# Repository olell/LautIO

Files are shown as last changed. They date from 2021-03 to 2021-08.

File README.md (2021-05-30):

# LautIO
Mobile PA-System solution

## Hardware Features

- [x] ESP32 (WiFi + Bluetooth)
- [x] ADAU1701 Digital Signal Processor
- [x] 12V, 5V & 3.3V Power Supply from Battery
- [x] 2x TPA3255-Q1 Amplifier (615W each -> 1260W Amp Power)
- [x] USB Ports to charge mobile phones, etc.
- [x] SD Card socket

## Fancy Rendering
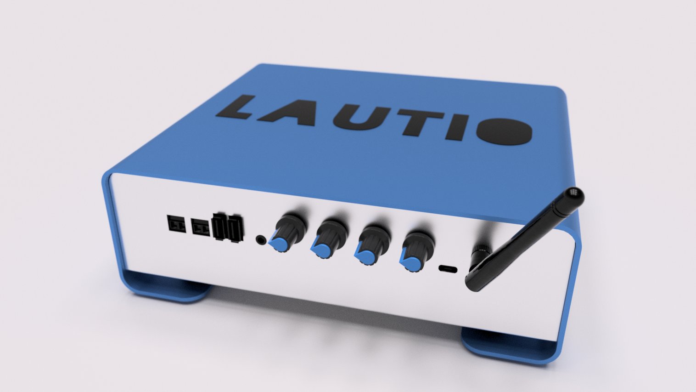
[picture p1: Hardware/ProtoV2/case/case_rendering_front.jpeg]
LautIO Rendering


## Third party resources
This git repository contains links or files of the following projects:
* `Bootstrap 5` released under the MIT license. (c) 2021 Twitter
* `Bootswach` released under the MIT license. (c) 2021 Thomas Park
* `jQuery 3.6.0` released under the MIT license. (c) 2021 OpenJS Foundation
* `PlatformIO` released under the Apache 2.0 license. (c) 2021 PlatformIO
* `ESPAsyncTCP` released under the GNU LGPL license. (c) 2021 https://github.com/me-no-dev
* `ESPAsyncWebServer` released under the GNU LGPL license. (c) 2021 https://github.com/me-no-dev
* `SigmaDSP library` released under the GNU LGPL license. (c) 2021 https://github.com/MCUdude
* `ArduinoJson library` released under the MIT license. (c) 2021 Benoît Blanchon

## License
MIT License

Copyright (c) 2021 olel

Permission is hereby granted, free of charge, to any person obtaining a copy
of this software and associated documentation files (the "Software"), to deal
in the Software without restriction, including without limitation the rights
to use, copy, modify, merge, publish, distribute, sublicense, and/or sell
copies of the Software, and to permit persons to whom the Software is
furnished to do so, subject to the following conditions:

The above copyright notice and this permission notice shall be included in all
copies or substantial portions of the Software.

THE SOFTWARE IS PROVIDED "AS IS", WITHOUT WARRANTY OF ANY KIND, EXPRESS OR
IMPLIED, INCLUDING BUT NOT LIMITED TO THE WARRANTIES OF MERCHANTABILITY,
FITNESS FOR A PARTICULAR PURPOSE AND NONINFRINGEMENT. IN NO EVENT SHALL THE
AUTHORS OR COPYRIGHT HOLDERS BE LIABLE FOR ANY CLAIM, DAMAGES OR OTHER
LIABILITY, WHETHER IN AN ACTION OF CONTRACT, TORT OR OTHERWISE, ARISING FROM,
OUT OF OR IN CONNECTION WITH THE SOFTWARE OR THE USE OR OTHER DEALINGS IN THE
SOFTWARE.

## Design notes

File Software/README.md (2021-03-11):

# LautI/O Software

This directory contains thie soft-/ firmware.

* `LautIO/`: This is the PlatformIO firmware project for the esp32

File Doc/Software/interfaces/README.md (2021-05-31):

# Interfaces
You can control the LautIO via different interfaces..

following interfaces are currently implemented:
* Websockets

## Base structure
```JSON
{
    "category": "example",
    "command": "example_command",
    "parameter": "xyz",
    "more_param": 123,
    "value": true
}
```

## Categories
* [`DSP`](dsp.md)

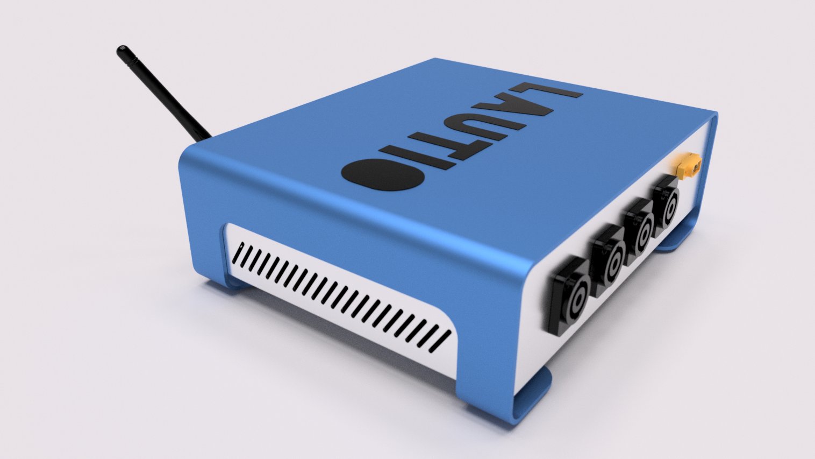
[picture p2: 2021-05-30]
Hardware/ProtoV2/case/case_rendering_back.jpeg

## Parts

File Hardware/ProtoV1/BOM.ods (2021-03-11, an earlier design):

Part | Value | Package | Amount | Mouser No. |  | Labels
 |  |  | 169
Electrolytic Cap | 10000 µF | EB35D | 1 | 80-ALC10S1103DH | Mouser Link (https://www.mouser.de/ProductDetail/) | C1
Electrolytic Cap | 10 µF | 153CLV-0605 | 3 | 667-EEE-FN1J100L | Mouser Link (https://www.mouser.de/ProductDetail/) | C2, C10, C11
Cap | 1.2 nF | 0603 | 1 | 80-C0603C122K5R | Mouser Link (https://www.mouser.de/ProductDetail/) | C3
Cap | 6.8 pF | 0603 | 1 | 80-C0603C689K5G | Mouser Link (https://www.mouser.de/ProductDetail/) | C4
Cap | 100 nF | 0603 | 26 | 80-C0603C104M5R | Mouser Link (https://www.mouser.de/ProductDetail/) | C5, C7, C9, C14-C21, C27, C29, C31, C43, C45, C46, C48, C52, C54, C67, C69, C70, C72, C76, C78
Electrolytic Cap | 47 µF | 153CLV-0807 | 1 | 667-EEE-FK1J470L | Mouser Link (https://www.mouser.de/ProductDetail/) | C6
Cap | 2.2 nF | 0603 | 1 | 80-C0603C222M5R | Mouser Link (https://www.mouser.de/ProductDetail/) | C8
Polarized Cap | 10 µF | 1206 | 11 | 187-CL31A106KBHNNNE | Mouser Link (https://www.mouser.de/ProductDetail/) | C12, C13, C22-C24, C28, C30, C44, C47, C68, C71
Cap | 22 pF | 0603 | 2 | 80-C0603C220M5HACTU | Mouser Link (https://www.mouser.de/ProductDetail/) | C25, C26
Polarized Cap | 47 µF | 1206 | 1 | 963-EMK316BBJ476ML-T | Mouser Link (https://www.mouser.de/ProductDetail/) | C32
Cap | 3.3 nF | 0603 | 1 | 80-C0603C332K5R | Mouser Link (https://www.mouser.de/ProductDetail/) | C33
Cap | 56 nF | 0603 | 1 | 80-C0603C563K5RAUTO | Mouser Link (https://www.mouser.de/ProductDetail/) | C34
Electrolytic Cap | 47 µF | CLV-0605 | 4 | EEE-FK1V470AL | Mouser Link (https://www.mouser.de/ProductDetail/) | C35, C37, C39, C41
Cap | 5.6 nF | 0603 | 4 | 80-C0603C562K5R | Mouser Link (https://www.mouser.de/ProductDetail/) | C36, C38, C40, C42
Electrolytic Cap | 1000 µF | E7,5-16 | 4 | 667-ECA-1JM102B | Mouser Link (https://www.mouser.de/ProductDetail/) | C49, C50, C73, C74
Cap | 1 µF | 0603 | 4 | 581-06035D105MAT2A | Mouser Link (https://www.mouser.de/ProductDetail/) | C51, C53, C75, C77
Cap | 1 µF | C3640 | 4 | 505-SMDTD04100XAKT00 | Mouser Link (https://www.mouser.de/ProductDetail/) | C60, C62, C84, C86
Cap | 330 pF | 0603 | 4 | 80-C0603C331M5HACTU | Mouser Link (https://www.mouser.de/ProductDetail/) | C55, C61, C79, C85
Cap | 220 nF | 0603 | 16 | 810-C1608X7R1H224K | Mouser Link (https://www.mouser.de/ProductDetail/) | C56-C59, C63-C66, C80-C83, C87-C90
Diode | STPS20M100SG-TR | D²PAK | 1 | 511-STPS20M100SG-TR | Mouser Link (https://www.mouser.de/ProductDetail/) | D1
ESP 32 |  |  | 1 | Nope don’t buy this at mouser :P | Mouser Link (https://www.mouser.de/ProductDetail/) | ESP
Regulator | *1117 | SOT223 | 1 | 511-LDL1117S33R | Mouser Link (https://www.mouser.de/ProductDetail/) | IC1
Inductor | 15 µH | 4747 | 1 | 994-MSS1210-153MEB | Mouser Link (https://www.mouser.de/ProductDetail/) | L1
Inductor | 1 µH |  | 1 | 710-74438357010 | Mouser Link (https://www.mouser.de/ProductDetail/) | L2
Inductor | L3-L10 |  | 8 | 710-744770115 | Mouser Link (https://www.mouser.de/ProductDetail/) | L3-L10
Transistor | ZX5T953 | SOT223 | 1 | 522-ZX5T953GTA | Mouser Link (https://www.mouser.de/ProductDetail/) | Q1
Crystal | 12.288 Mhz | ? | 1 | 520-122.8-20-3XENT | Mouser Link (https://www.mouser.de/ProductDetail/) | Q2
Regulator | TPS54560B-Q1 | HSOP8 | 1 | 595-TPS54560BQDDARQ1 | Mouser Link (https://www.mouser.de/ProductDetail/) | REG1
Regulator | TPS621351RGXR | RGX0011A ??? | 1 | 595-TPS621351RGXT | Mouser Link (https://www.mouser.de/ProductDetail/) | REG2
Momentary Switch |  | ? | 2 | 612-LL3303F065QG | Mouser Link (https://www.mouser.de/ProductDetail/) | S1, S2
XT60 |  | XT60 | 1 | 426-FIT0587 | Mouser Link (https://www.mouser.de/ProductDetail/) | U$1
Heatsink | ATS-CPX030030030 |  | 2 | 984-CPX03003-173C2R0 | Mouser Link (https://www.mouser.de/ProductDetail/) | U$2, U§3
DSP | ADAU1701 | ST_48_ADI ??? | 1 | 584-ADAU1701JSTZ | Mouser Link (https://www.mouser.de/ProductDetail/) | U1
Amp | TDA7498ETR | SSO36 | 2 | 511-TDA7498ETR | Mouser Link (https://www.mouser.de/ProductDetail/) | U2, U3
Connector | MKDSN1,5/2-5,08 | ? | 1 | 651-1985865 | Mouser Link (https://www.mouser.de/ProductDetail/) | X1
USB | Type A Up Right | ? | 2 | 649-73725-0110BLF | Mouser Link (https://www.mouser.de/ProductDetail/) | J1, J2
3.5 mm Jack | SJ1-3523N | CUI_SJ1-3523N | 1 | 490-SJ1-3523N | Mouser Link (https://www.mouser.de/ProductDetail/) | J5
Resistor | 187 kΩ | 0603 | 1 | 667-ERJ-3EKF1873V | Mouser Link (https://www.mouser.de/ProductDetail/) | R1
Resistor | 44.2 kΩ | 0603 | 1 | 667-ERJ-3EKF4422V | Mouser Link (https://www.mouser.de/ProductDetail/) | R2
Resistor | 147 kΩ | 0603 | 1 | 667-ERJ-3EKF1473V | Mouser Link (https://www.mouser.de/ProductDetail/) | R3
Resistor | 10.5 kΩ | 0603 | 1 | 667-ERJ-3EKF1052V | Mouser Link (https://www.mouser.de/ProductDetail/) | R4
Resistor | 100 kΩ | 0603 | 8 | 71-CRCW0603100KFKEAC | Mouser Link (https://www.mouser.de/ProductDetail/) | R5, R6, R31-R33, R45-R47
Resistor | 619 kΩ | 0603 | 1 | 667-ERJ-3EKF6193V | Mouser Link (https://www.mouser.de/ProductDetail/) | R7
Resistor | 10 kΩ | 0603 | 8 | 667-ERJ-3GEYJ103V | Mouser Link (https://www.mouser.de/ProductDetail/) | R8, R16, R26, R27, R30, R40, R41, R44
Resistor | 4.7 kΩ | 0603 | 2 | 667-ERJ-3EKF4701V | Mouser Link (https://www.mouser.de/ProductDetail/) | R13, R14
Resistor | 1 kΩ | 0603 | 1 | 71-CRCW06031K00JNEAC | Mouser Link (https://www.mouser.de/ProductDetail/) | R15
Resistor | 18 kΩ | 0603 | 3 | 667-ERJ-3EKF1802V | Mouser Link (https://www.mouser.de/ProductDetail/) | R17-R19
Resistor | 100 Ω | 0603 | 1 | 667-ERJ-3EKF1000V | Mouser Link (https://www.mouser.de/ProductDetail/) | R20
Resistor | 475 Ω | 0603 | 1 | 667-ERJ-3EKF4750V | Mouser Link (https://www.mouser.de/ProductDetail/) | R21
Resistor | 560 Ω | 0603 | 1 | 667-ERJ-3EKF5600V | Mouser Link (https://www.mouser.de/ProductDetail/) | R22-R25
Resistor | 22 Ω | 0603 | 6 | 667-ERJ-3EKF22R0V | Mouser Link (https://www.mouser.de/ProductDetail/) | R28, R34, R37, R42, R48, R51
Resistor | 47 kΩ | 0603 | 2 | 667-ERJ-3RBD4702V | Mouser Link (https://www.mouser.de/ProductDetail/) | R29, R43
Resistor | 8 Ω | 0603 | 8 | 71-CRCW06038R06FKEA | Mouser Link (https://www.mouser.de/ProductDetail/) | R35, R36, R38, R39, R49, R50, R52, R53
Potentiometer | 10 kΩ |  | 4 | 858-P160KN0QD15B10K | Mouser Link (https://www.mouser.de/ProductDetail/) | R9-R12

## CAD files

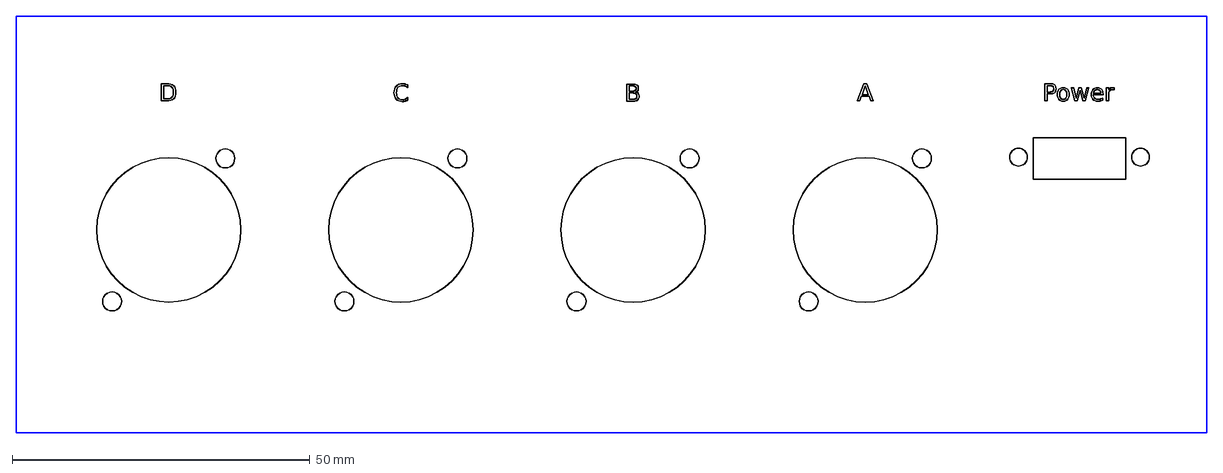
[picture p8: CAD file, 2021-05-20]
Hardware/ProtoV2/case/panel_rear_cutouts.dxf
199.9 x 69.9 mm

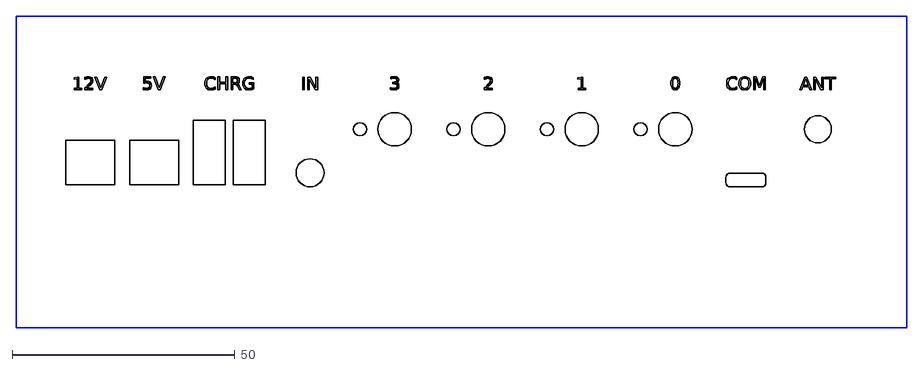
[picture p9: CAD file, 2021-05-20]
Hardware/ProtoV2/case/panel_front_cutouts.dxf
199.9 x 69.9

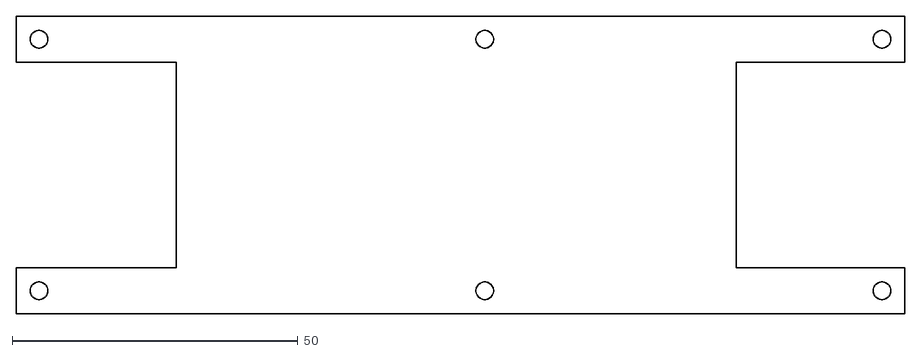
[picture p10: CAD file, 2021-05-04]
Hardware/ProtoV2/case/pipemount.dxf
155.5 x 52.0

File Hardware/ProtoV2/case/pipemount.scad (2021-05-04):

/*
 *
 * This file is part of LautIO
 *
 * Copyright 2021 - olel
 * LautIO is licensed under MIT License
 * See LICENSE file for more information
 * 
 */
 
 $fn = 60;
 
 plate_width           = 155.50;
 plate_height          = 52.00;
 
 screw_size            = 3.10;
 screw_distance        = 4.00;
 middle_screw_distance = 78.00;
 
 cutout_left_width     = 28.00;
 cutout_right_width    = 29.50;
 
 module pipemount() {
     difference() {
        
         // ground plane
         square([plate_width, plate_height]);
         
         union() {
             
             // screw holes
             translate([screw_distance, screw_distance])
             circle(d=screw_size);
             
             translate([screw_distance + middle_screw_distance, screw_distance])
             circle(d=screw_size);
             
             translate([plate_width - screw_distance, screw_distance])
             circle(d=screw_size);
             
             translate([plate_width - screw_distance, plate_height - screw_distance])
             circle(d=screw_size);
             
             translate([screw_distance, plate_height - screw_distance])
             circle(d=screw_size);
             
             translate([screw_distance + middle_screw_distance, plate_height - screw_distance])
             circle(d=screw_size);
             
             // left cutout
             translate([0, screw_distance * 2])
             square([cutout_left_width, plate_height - (screw_distance * 4)]);
             
             // right cutout
             translate([plate_width - cutout_right_width, screw_distance * 2])
             square([cutout_right_width, plate_height - (screw_distance * 4)]);
             
             
         }
     }
     
 }
 
 pipemount();

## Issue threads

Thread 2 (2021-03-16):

Cascading

olell, 2021-03-16:
Cascading von mehreren LautIO boards via SPDIF bzw. Toslink

olell, 2021-04-12:
Via I2S in protov2 schematic angepasst

Closed 2021-04-12.

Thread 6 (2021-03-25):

DSP Reset auf GPIO12

olell, 2021-03-25:
Flashen funktioniert mit DSP Reset auf GPIO12 nicht..

olell, 2021-04-12:
In protov2 schematic angepasst

Closed 2021-04-12.

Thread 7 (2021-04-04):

WiFi connect nur jedes zweite Mal

olell, 2021-04-04:
Könnte etwas ähnliches wie dieses sein: https://github.com/espruino/Espruino/issues/1168

olell, 2021-04-21:
Schreibe die software jetze eh neu, also erstmal geschlossen :)

Closed 2021-04-21.

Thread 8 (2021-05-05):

VBAT_MEASURE offset

olell, 2021-05-05:
Der VBAT_MEASURE OpAmp packt irgendwie nen Offset auf die geteilte Akkuspannung drauf.. lässt sich probably mit software austarieren

olell, 2021-07-15:
Ist nen hardware fehler, für ProtoV2 ist die einfachste Lösung den OpAmp zwischen ESP und Spannungsteiler einfach rauszulassen und zu Brücken

Closed 2021-07-15.

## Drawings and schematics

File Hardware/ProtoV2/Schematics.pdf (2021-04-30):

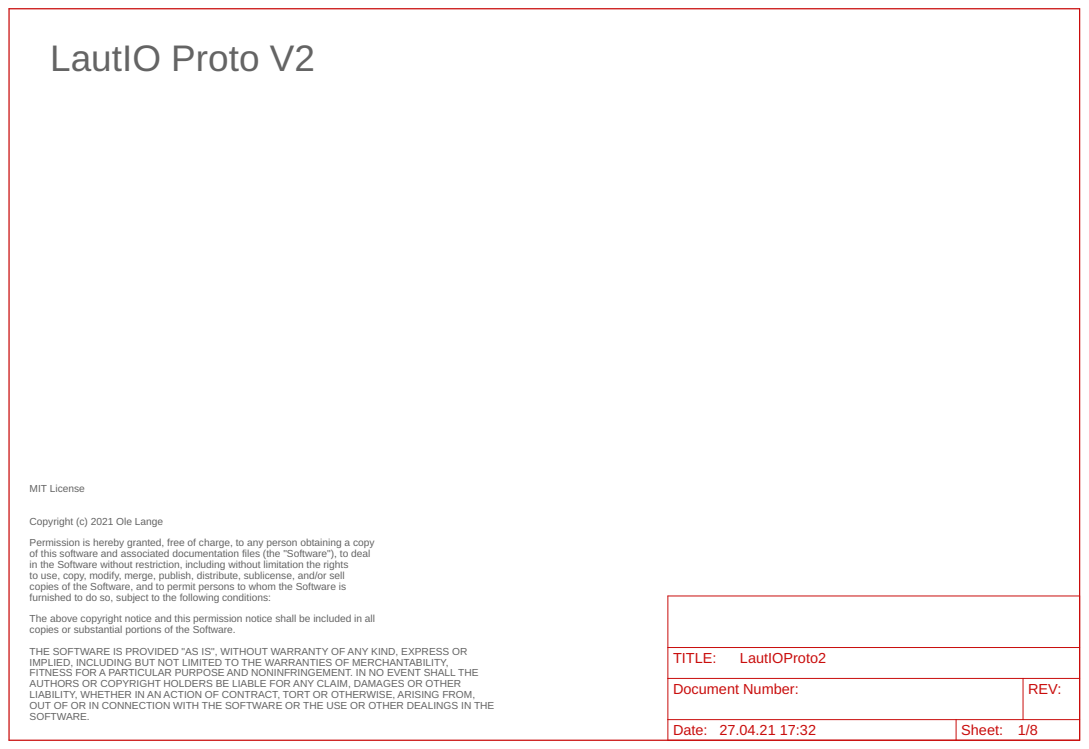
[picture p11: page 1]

MIT License Copyright (c) 2021 Ole Lange Permission is hereby granted, free of charge, to any person obtaining a copy of this software and associated documentation files (the "Software"), to deal

in the Software without restriction, including without limitation the rights
to use, copy, modify, merge, publish, distribute, sublicense, and/or sell copies of the Software, and to permit persons to whom the Software is

furnished to do so, subject to the following conditions: The above copyright notice and this permission notice shall be included in all copies or substantial portions of the Software. THE SOFTWARE IS PROVIDED "AS IS", WITHOUT WARRANTY OF ANY KIND, EXPRESS OR

IMPLIED, INCLUDING BUT NOT LIMITED TO THE WARRANTIES OF MERCHANTABILITY, FITNESS FOR A PARTICULAR PURPOSE AND NONINFRINGEMENT. IN NO EVENT SHALL THE

AUTHORS OR COPYRIGHT HOLDERS BE LIABLE FOR ANY CLAIM, DAMAGES OR OTHER
LIABILITY, WHETHER IN AN ACTION OF CONTRACT, TORT OR OTHERWISE, ARISING FROM, OUT OF OR IN CONNECTION WITH THE SOFTWARE OR THE USE OR OTHER DEALINGS IN THE

Document Number: | REV:

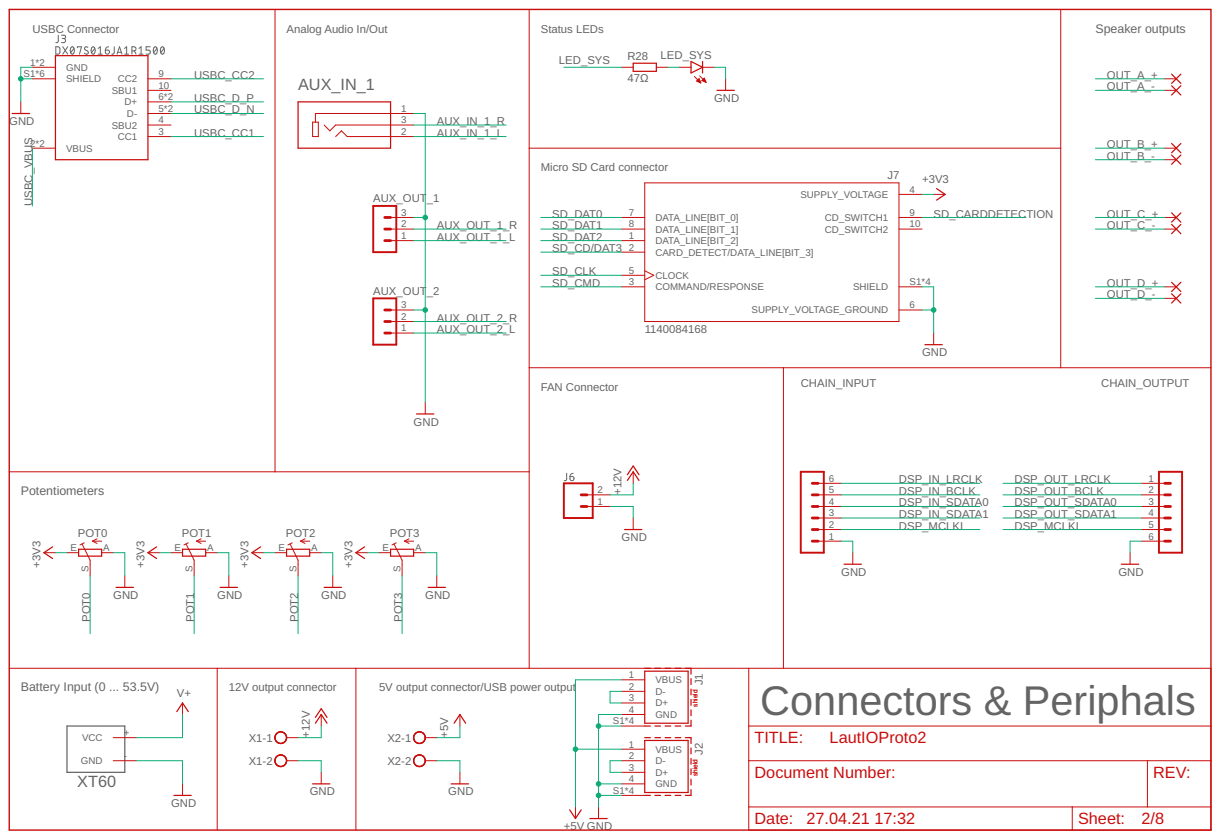
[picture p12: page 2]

Micro SD Card connector

5V output connector/USB power output

Document Number: | REV:

Date: | Sheet:

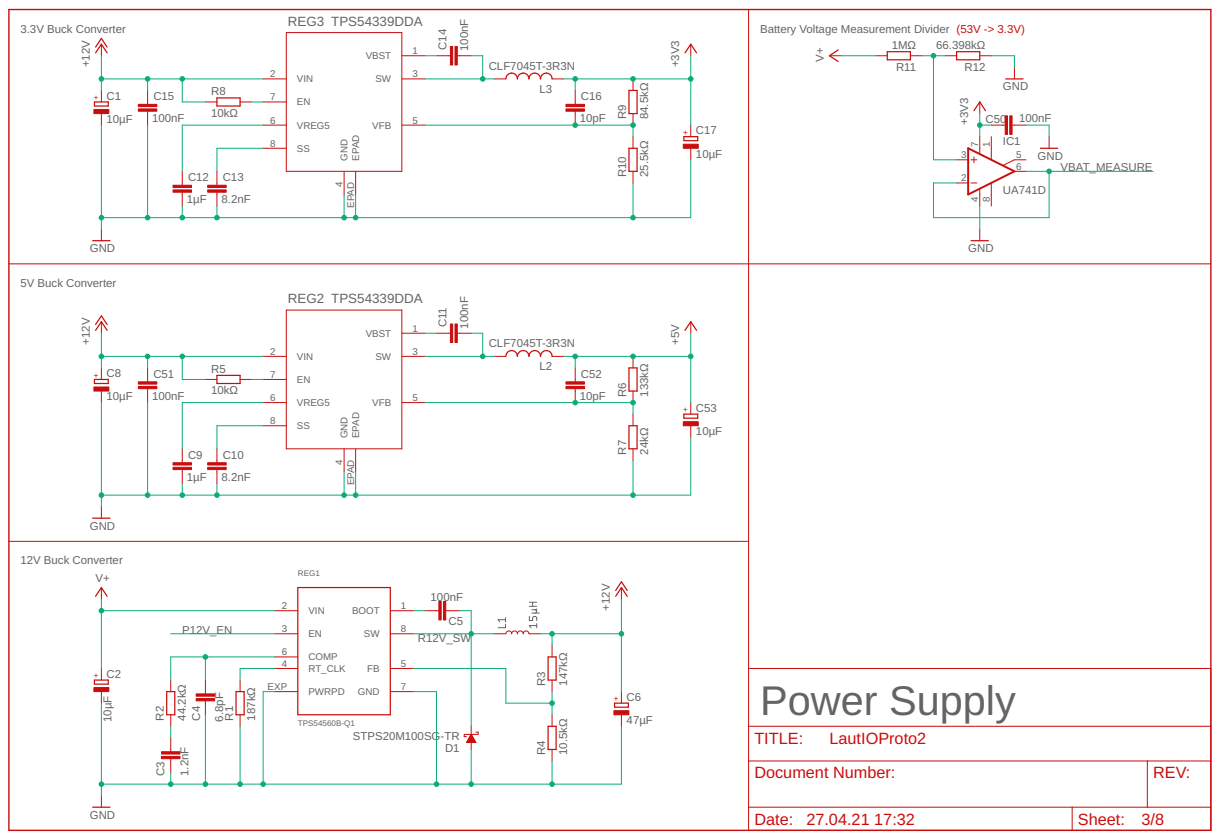
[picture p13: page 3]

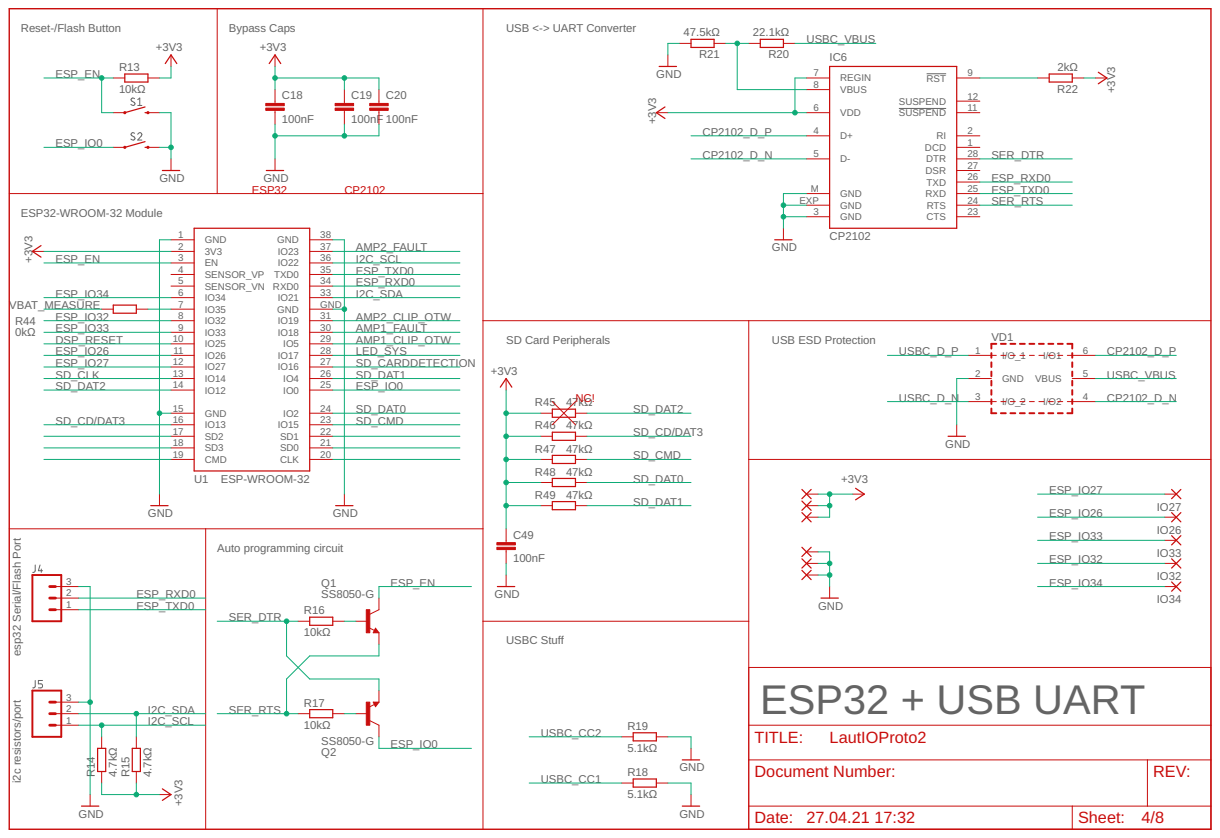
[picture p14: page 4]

esp32 Serial/Flash Port i2c resistors/port

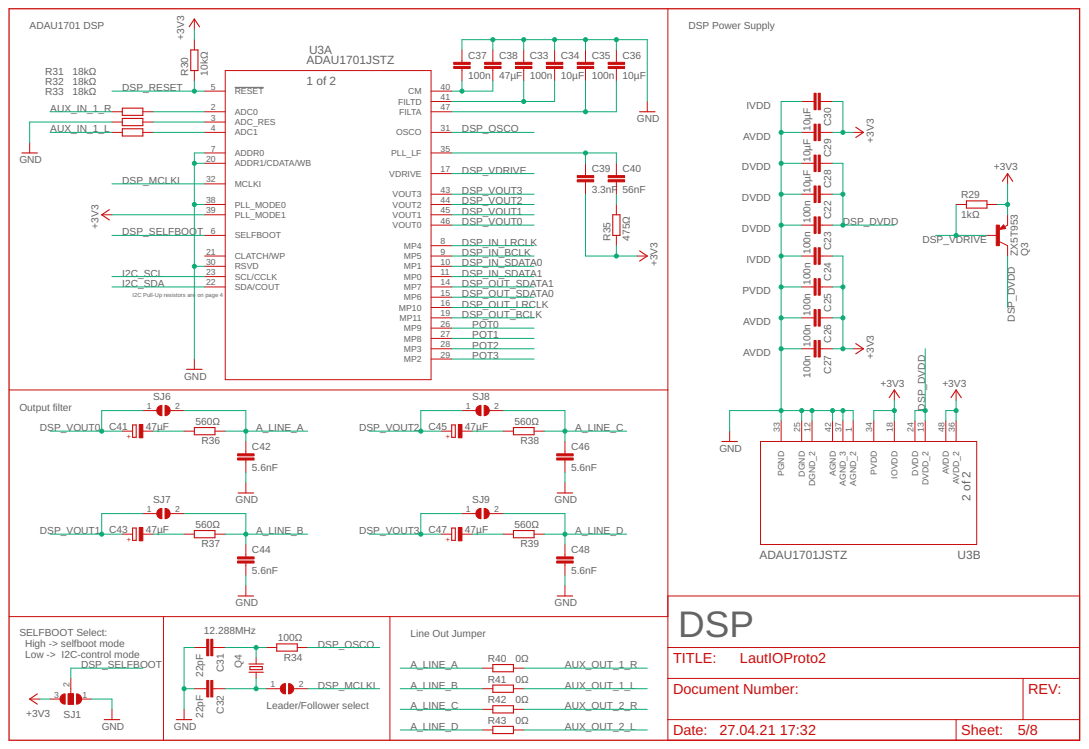
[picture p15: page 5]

I2C Pull-Up resistors are on page 4

SELFBOOT Select: High -> selfboot mode

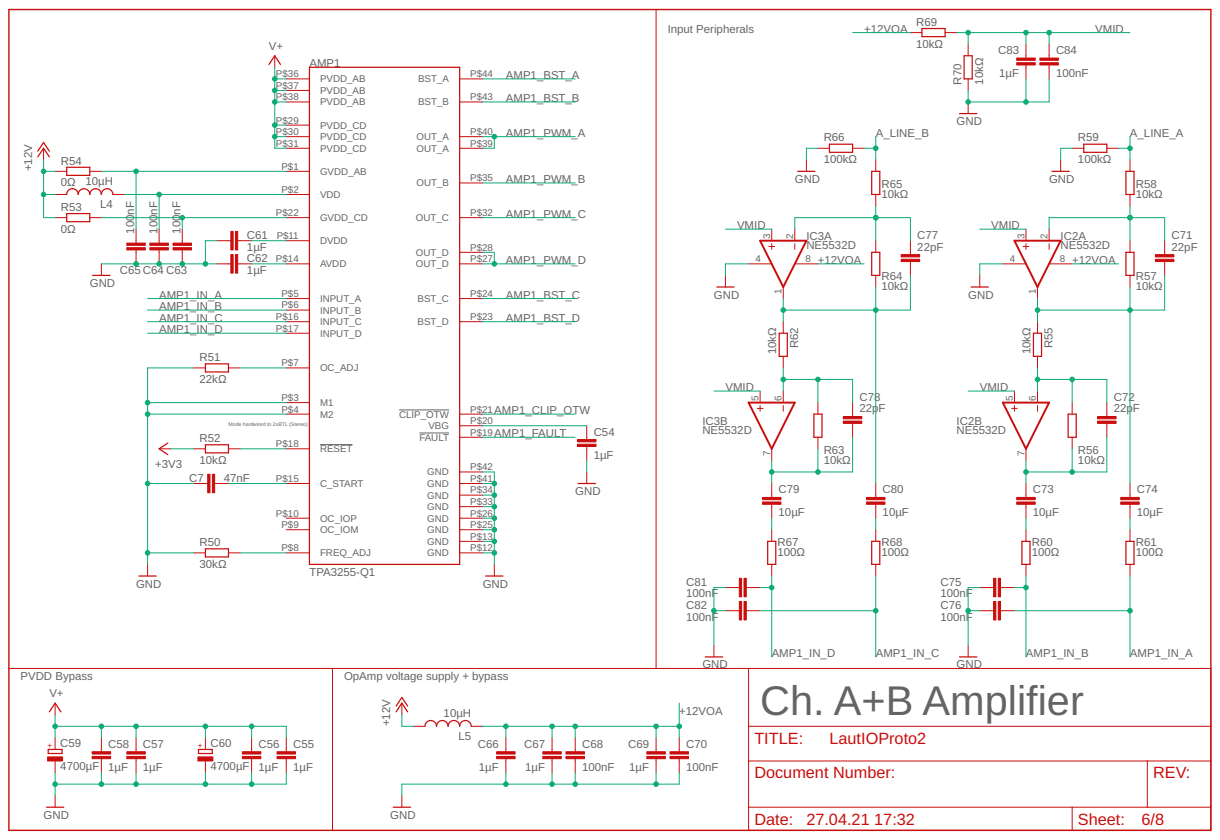
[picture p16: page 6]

Mode hardwired to 2xBTL (Stereo)

OpAmp voltage supply + bypass

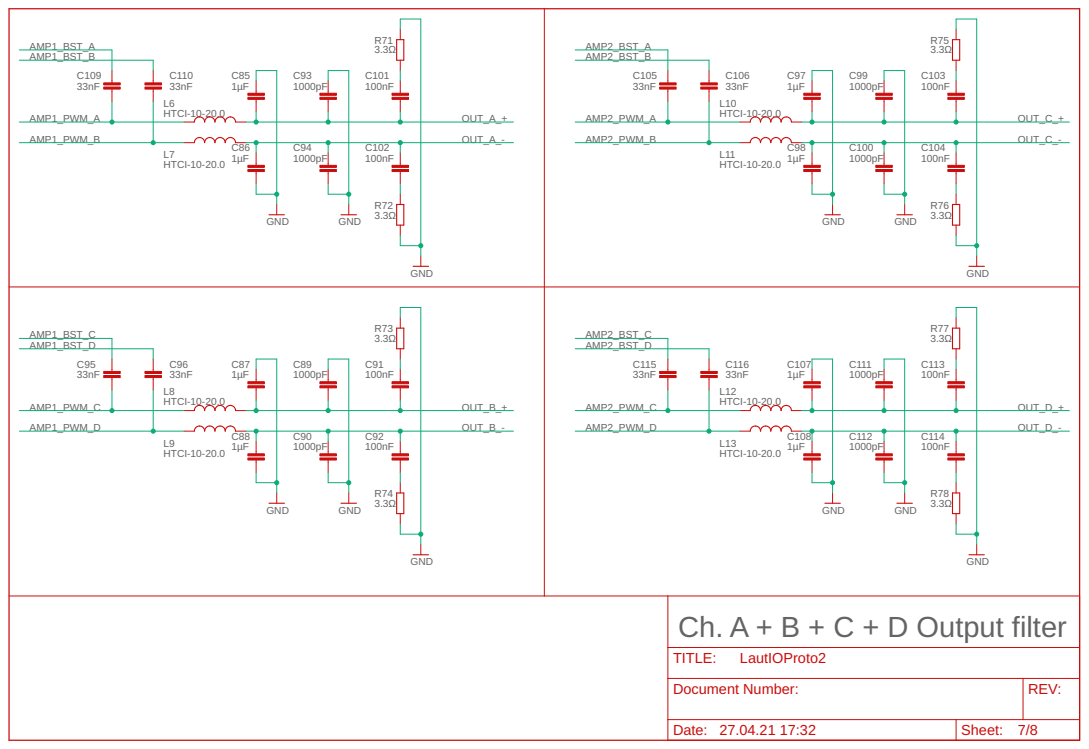
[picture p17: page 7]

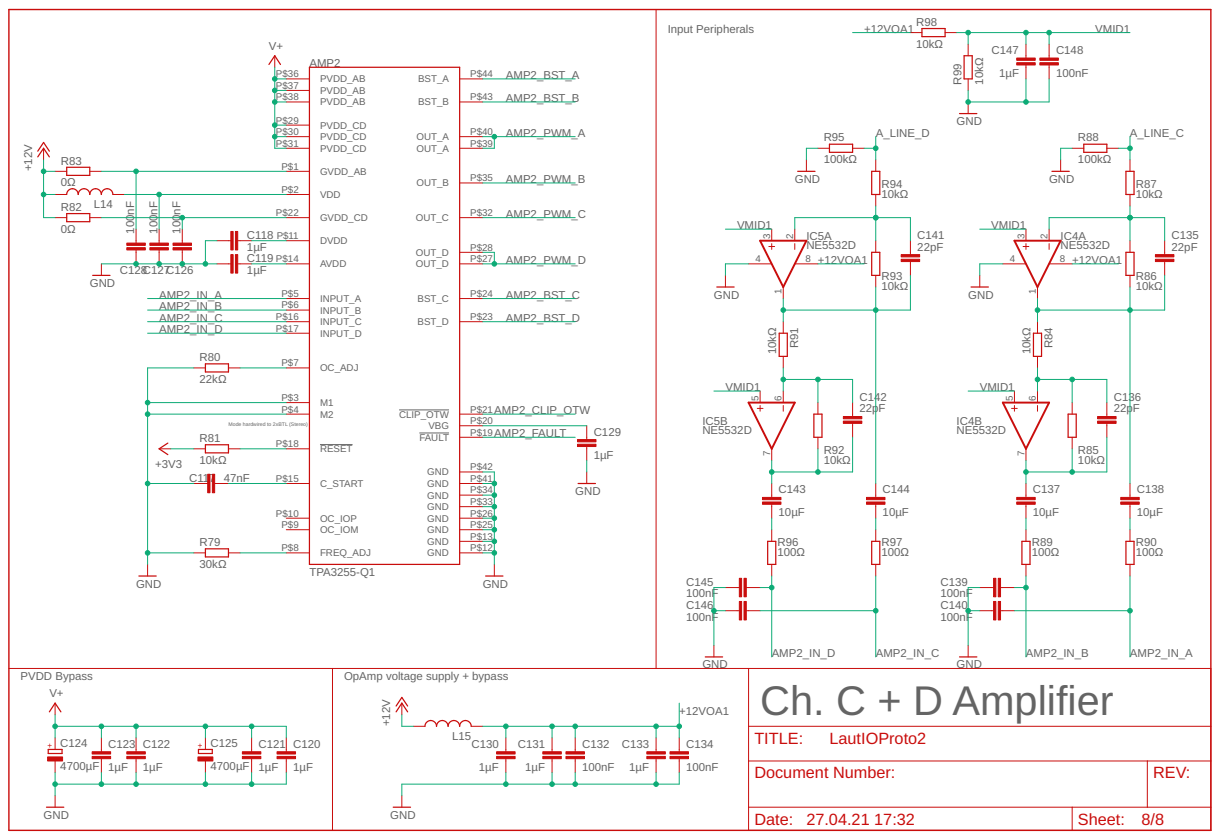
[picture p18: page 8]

Mode hardwired to 2xBTL (Stereo)

OpAmp voltage supply + bypass

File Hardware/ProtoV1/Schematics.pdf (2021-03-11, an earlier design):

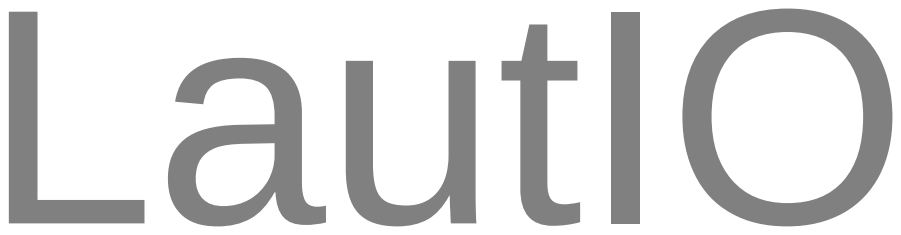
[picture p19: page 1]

Document Number: | REV:

Date: 11.03.21 11:48 | Sheet: 1/7

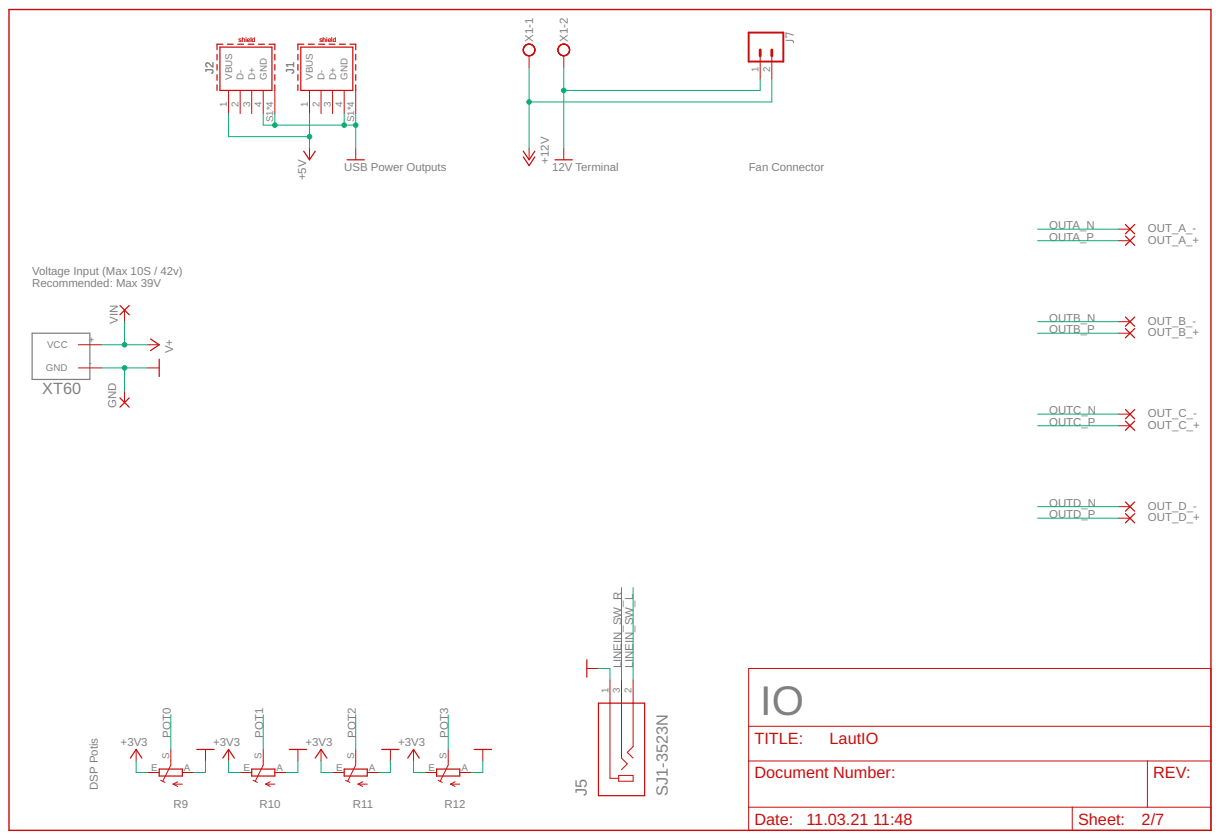
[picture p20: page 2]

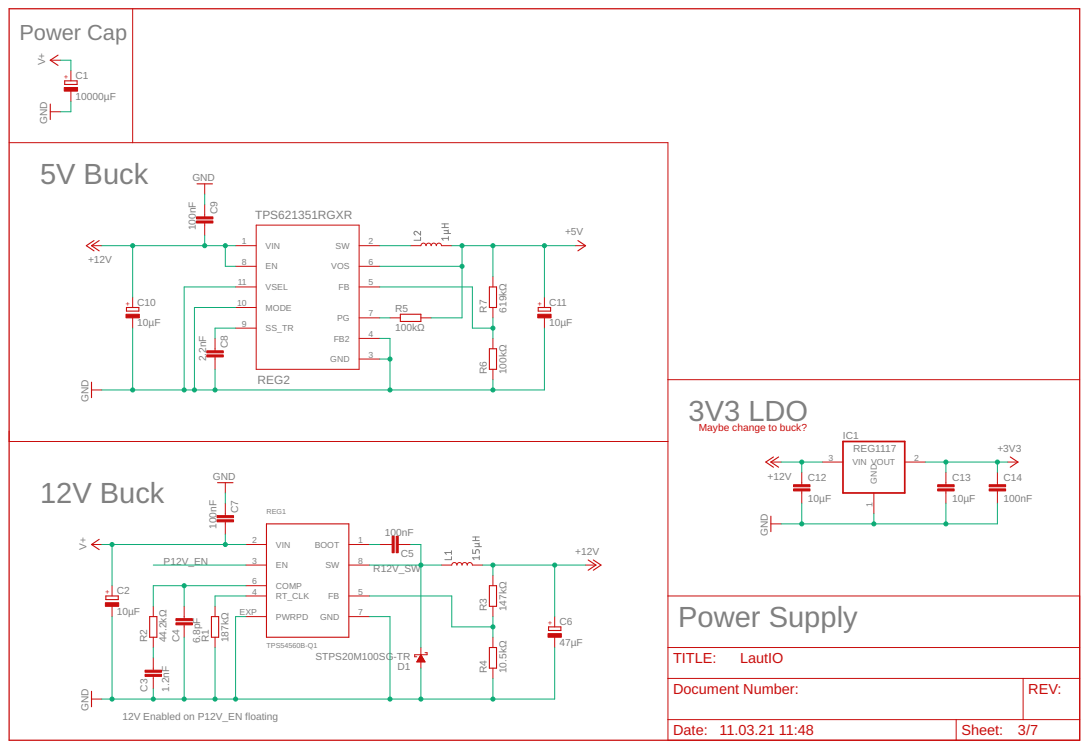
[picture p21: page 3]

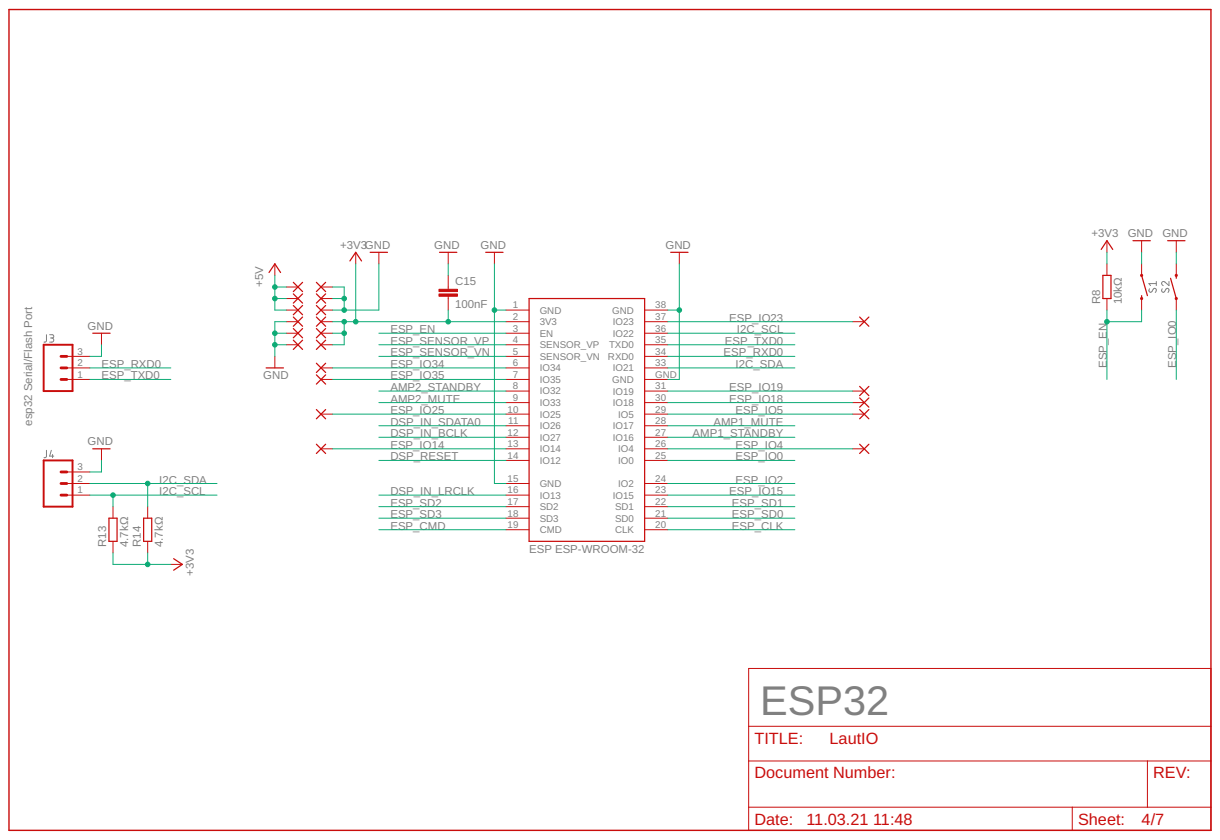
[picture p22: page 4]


I2C Pull-Up resistors are on page 4

SELFBOOT Select: High -> selfboot mode


33 | 9 | AMP1_OUTA_N
22 | 10

EPAD | 3 | AMP1_OUTA_P
30 | 16

35 | | 7
29 | | 12
25 | | 13


33 | 9 | AMP2_OUTA_N
22 | 10

EPAD | 3 | AMP2_OUTA_P
30 | 16

35 | | 7
29 | | 12
25 | | 13

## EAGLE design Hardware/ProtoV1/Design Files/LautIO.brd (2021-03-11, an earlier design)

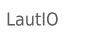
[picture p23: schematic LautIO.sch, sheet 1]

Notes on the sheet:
LautIO

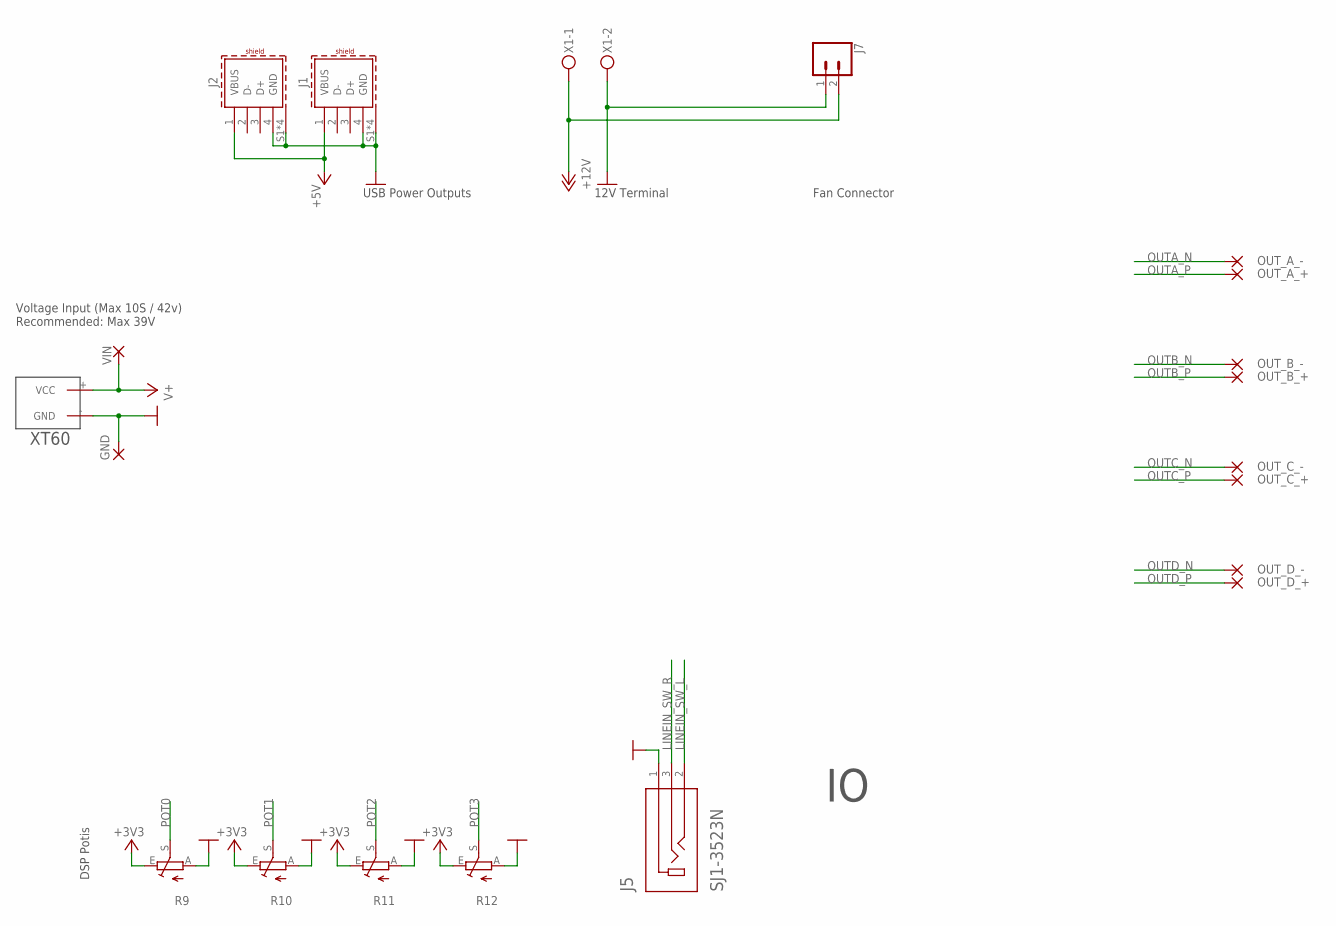
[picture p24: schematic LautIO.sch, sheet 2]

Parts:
GND: SMD5; SMD2,54-5,08
J1, J2: 614004134726
J5: SJ1-3523N; CUI_SJ1-3523N
J7: CONN_02; 1X02
OUT_A_+: SMD2; SMD1,27-2,54
OUT_A_-: SMD2; SMD1,27-2,54
OUT_B_+: SMD2; SMD1,27-2,54
OUT_B_-: SMD2; SMD1,27-2,54
OUT_C_+: SMD2; SMD1,27-2,54
OUT_C_-: SMD2; SMD1,27-2,54
OUT_D_+: SMD2; SMD1,27-2,54
OUT_D_-: SMD2; SMD1,27-2,54
R9, R10, R11, R12: TRIM_EU-CIP20C-6MM; CIP20C-6MM
U$1: XT60
VIN: SMD5; SMD2,54-5,08
X1: MKDSN1,5/2-5,08

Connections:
+3V3: R9.E, R10.E, R11.E, R12.E; also elsewhere on the board
+5V: J1.1 (VBUS), J2.1 (VBUS); also elsewhere on the board
+12V: J7.2, X1.1; also elsewhere on the board
GND: GND.1, J1.4 (GND), J1.S1 (SHIELD), J1.S2 (SHIELD), J1.S3 (SHIELD), J1.S4 (SHIELD), J2.4 (GND), J2.S1 (SHIELD), J2.S2 (SHIELD), J2.S3 (SHIELD), J2.S4 (SHIELD), J5.1, J7.1, R9.A, R10.A, R11.A, R12.A, U$1.- (GND), X1.2; also elsewhere on the board
LINEIN_SW_L: J5.2; also elsewhere on the board
LINEIN_SW_R: J5.3; also elsewhere on the board
OUTA_N: OUT_A_-.1; also elsewhere on the board
OUTA_P: OUT_A_+.1; also elsewhere on the board
OUTB_N: OUT_B_-.1; also elsewhere on the board
OUTB_P: OUT_B_+.1; also elsewhere on the board
OUTC_N: OUT_C_-.1; also elsewhere on the board
OUTC_P: OUT_C_+.1; also elsewhere on the board
OUTD_N: OUT_D_-.1; also elsewhere on the board
OUTD_P: OUT_D_+.1; also elsewhere on the board
POT0: R9.S; also elsewhere on the board
POT1: R10.S; also elsewhere on the board
POT2: R11.S; also elsewhere on the board
POT3: R12.S; also elsewhere on the board
V+: U$1.+ (VCC), VIN.1; also elsewhere on the board

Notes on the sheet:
USB Power Outputs
Voltage Input (Max 10S / 42v) Recommended: Max 39V
12V Terminal
DSP Potis
Fan Connector

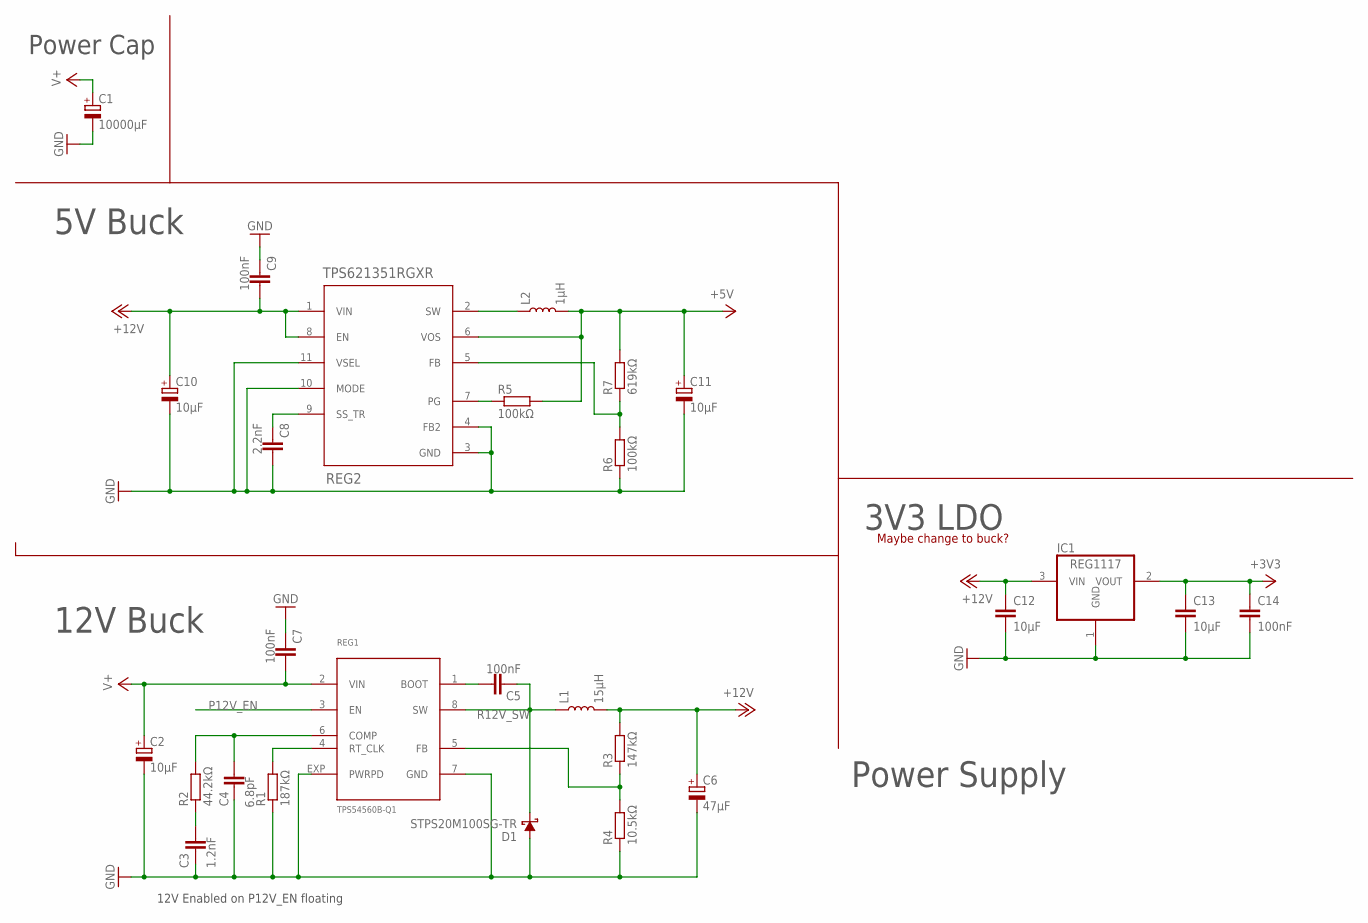
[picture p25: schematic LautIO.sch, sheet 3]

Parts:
C1: 10000µF; EB35D
C2, C10, C11: 10µF; 153CLV-0605
C3: 1.2nF; C0603
C4: 6.8pF; C0603
C5, C7, C9, C14: 100nF; C0603
C6: 47µF; 153CLV-0807
C8: 2.2nF; C0603
C12, C13: 10µF; C1206
D1: STPS20M100SG-TR; TO-263/D2PAK
IC1: REG1117; SOT223
L1: 15µH; INDUCTOR_SDR1307
L2: 1µH; INDUCTOR_4X4MM
R1: 187kΩ; R0603
R2: 44.2kΩ; R0603
R3: 147kΩ; R0603
R4: 10.5kΩ; R0603
R5, R6: 100kΩ; R0603
R7: 619kΩ; R0603
REG1: TPS54560B-Q1; HSOP8
REG2: TPS621351RGXR; RGX0011A

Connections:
+3V3: C13.1, C14.1, IC1.2 (VOUT); also elsewhere on the board
+5V: C11.+, L2.P$2 (2), R5.2, R7.2, REG2.6 (VOS); also elsewhere on the board
+12V: C6.+, C9.1, C10.+, C12.1, IC1.3 (VIN), L1.P$2 (2), R3.2, REG2.1 (VIN), REG2.8 (EN); also elsewhere on the board
GND: C1.-, C2.-, C3.2, C4.2, C6.-, C7.2, C8.1, C9.2, C10.-, C11.-, C12.2, C13.2, C14.2, D1.1 (A), D1.3 (A), IC1.1 (GND), R1.1, R4.1, R6.1, REG1.7 (GND), REG1.EXP (PWRPD), REG2.3 (GND), REG2.4 (FB2), REG2.10 (MODE), REG2.11 (VSEL); also elsewhere on the board
unnamed: R1.2, REG1.4 (RT_CLK)
unnamed: C4.1, R2.2, REG1.6 (COMP)
unnamed: C3.1, R2.1
unnamed: C5.1, REG1.1 (BOOT)
unnamed: R6.2, R7.1, REG2.5 (FB)
unnamed: R3.1, R4.2, REG1.5 (FB)
unnamed: L2.P$1 (1), REG2.2 (SW)
unnamed: R5.1, REG2.7 (PG)
unnamed: C8.2, REG2.9 (SS_TR)
P12V_EN: REG1.3 (EN)
R12V_SW: C5.2, D1.2 (C), L1.P$1 (1), REG1.8 (SW)
V+: C1.+, C2.+, C7.1, REG1.2 (VIN); also elsewhere on the board

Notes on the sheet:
Power Supply
Power Cap
12V Enabled on P12V_EN floating
12V Buck
5V Buck
3V3 LDO
Maybe change to buck?

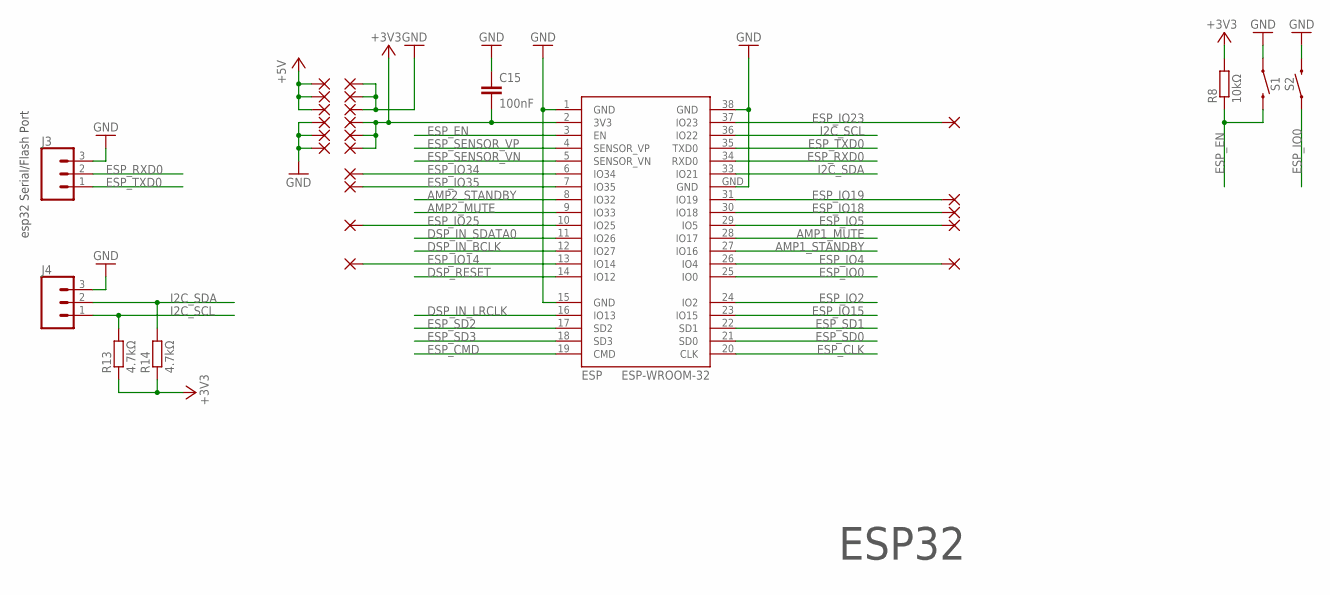
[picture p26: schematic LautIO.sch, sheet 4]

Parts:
C15: 100nF; C0603
ESP: ESP-WROOM-32
IO4, IO5, IO14, IO18, IO19, IO23, IO25, IO34, IO35: SMD2; SMD1,27-2,54
J3, J4: 455-1750-1-ND; 1X03
PAD1, PAD2, PAD3, PAD4, PAD5, PAD6, PAD7, PAD8, PAD9, PAD10, PAD11, PAD12: SMD2; SMD1,27-2,54
R8: 10kΩ; R0603
R13, R14: 4.7kΩ; R0603
S1, S2: MOMENTARY-SWITCH-SPST-SMD-6.2MM-TALL; TACTILE_SWITCH_SMD_6.2MM_TALL

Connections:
+3V3: C15.2, ESP.2 (3V3), PAD2.1, PAD4.1, PAD10.1, R8.2, R13.1, R14.1; also elsewhere on the board
+5V: PAD5.1, PAD6.1, PAD7.1; also elsewhere on the board
AMP1_MUTE: ESP.28 (IO17); also elsewhere on the board
AMP1_STANDBY: ESP.27 (IO16); also elsewhere on the board
AMP2_MUTE: ESP.9 (IO33); also elsewhere on the board
AMP2_STANDBY: ESP.8 (IO32); also elsewhere on the board
DSP_IN_BCLK: ESP.12 (IO27); also elsewhere on the board
DSP_IN_LRCLK: ESP.16 (IO13); also elsewhere on the board
DSP_IN_SDATA0: ESP.11 (IO26); also elsewhere on the board
DSP_RESET: ESP.14 (IO12); also elsewhere on the board
ESP_CLK: ESP.20 (CLK)
ESP_CMD: ESP.19 (CMD)
ESP_EN: ESP.3 (EN), R8.1, S1.B2 (2)
ESP_IO0: ESP.25 (IO0), S2.A2 (1)
ESP_IO2: ESP.24 (IO2)
ESP_IO4: ESP.26 (IO4), IO4.1
ESP_IO5: ESP.29 (IO5), IO5.1
ESP_IO14: ESP.13 (IO14), IO14.1
ESP_IO15: ESP.23 (IO15)
ESP_IO18: ESP.30 (IO18), IO18.1
ESP_IO19: ESP.31 (IO19), IO19.1
ESP_IO23: ESP.37 (IO23), IO23.1
ESP_IO25: ESP.10 (IO25), IO25.1
ESP_IO34: ESP.6 (IO34), IO34.1
ESP_IO35: ESP.7 (IO35), IO35.1
ESP_RXD0: ESP.34 (RXD0), J3.2
ESP_SD0: ESP.21 (SD0)
ESP_SD1: ESP.22 (SD1)
ESP_SD2: ESP.17 (SD2)
ESP_SD3: ESP.18 (SD3)
ESP_SENSOR_VN: ESP.5 (SENSOR_VN)
ESP_SENSOR_VP: ESP.4 (SENSOR_VP)
ESP_TXD0: ESP.35 (TXD0), J3.1
GND: C15.1, ESP.1 (GND), ESP.15 (GND), ESP.38 (GND), ESP.GND, J3.3, J4.3, PAD1.1, PAD3.1, PAD8.1, PAD9.1, PAD11.1, PAD12.1, S1.A2 (1), S2.B2 (2); also elsewhere on the board
I2C_SCL: ESP.36 (IO22), J4.1, R13.2; also elsewhere on the board
I2C_SDA: ESP.33 (IO21), J4.2, R14.2; also elsewhere on the board

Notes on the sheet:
ESP32
esp32 Serial/Flash Port

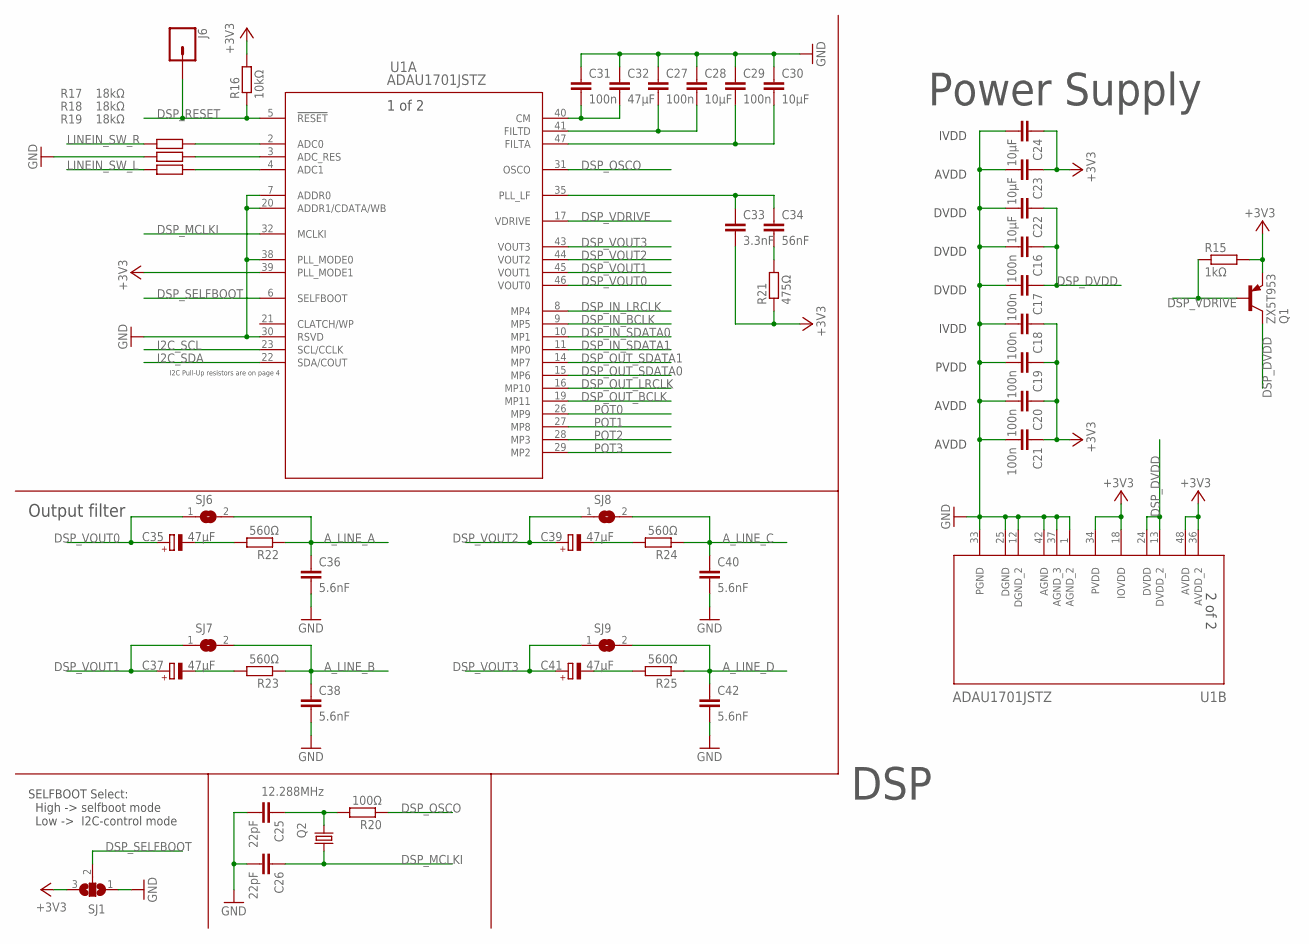
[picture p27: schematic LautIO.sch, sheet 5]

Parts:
C16, C17, C18, C19, C20, C21, C27, C29, C31: 100n; C0603
C22, C23, C24, C28, C30: 10µF; C1206K
C25, C26: 22pF; C0603
C32: 47µF; C1206K
C33: 3.3nF; C0603
C34: 56nF; C0603
C35, C37, C39, C41: 47µF; 153CLV-0605
C36, C38, C40, C42: 5.6nF; C0603
J6: CONN_01; 1X01
Q1: ZX5T953; SOT223
Q2: 12.288MHz; CSM-7X-DU
R15: 1kΩ; R0603
R16: 10kΩ; R0603
R17, R18, R19: 18kΩ; R0603
R20: 100Ω; R0603
R21: 475Ω; R0603
R22, R23, R24, R25: 560Ω; R0603
SJ1: SJ2W; SJ_2
SJ6, SJ7, SJ8, SJ9: SJ
U1: ADAU1701JSTZ; ST_48_ADI

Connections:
+3V3: C18.1, C19.1, C20.1, C21.1, C23.1, C24.1, C33.2, Q1.3 (E), R15.2, R16.2, R21.1, SJ1.3, U1.18 (IOVDD), U1.34 (PVDD), U1.36 (AVDD_2), U1.39 (PLL_MODE1), U1.48 (AVDD); also elsewhere on the board
A_LINE_A: C36.1, R22.1, SJ6.2; also elsewhere on the board
A_LINE_B: C38.1, R23.1, SJ7.2; also elsewhere on the board
A_LINE_C: C40.1, R24.1, SJ8.2; also elsewhere on the board
A_LINE_D: C42.1, R25.1, SJ9.2; also elsewhere on the board
DSP_DVDD: C16.1, C17.1, C22.1, Q1.2 (C), Q1.4 (C), U1.13 (DVDD_2), U1.24 (DVDD)
DSP_IN_BCLK: U1.9 (MP5); also elsewhere on the board
DSP_IN_LRCLK: U1.8 (MP4); also elsewhere on the board
DSP_IN_SDATA0: U1.10 (MP1); also elsewhere on the board
DSP_IN_SDATA1: U1.11 (MP0)
DSP_MCLKI: C26.1, Q2.1, U1.32 (MCLKI)
DSP_OSCO: R20.1, U1.31 (OSCO)
DSP_OUT_BCLK: U1.19 (MP11)
DSP_OUT_LRCLK: U1.16 (MP10)
DSP_OUT_SDATA0: U1.15 (MP6)
DSP_OUT_SDATA1: U1.14 (MP7)
DSP_RESET: J6.1, R16.1, U1.5 (!RESET); also elsewhere on the board
DSP_SELFBOOT: SJ1.2, U1.6 (SELFBOOT)
DSP_VDRIVE: Q1.1 (B), R15.1, U1.17 (VDRIVE)
DSP_VOUT0: C35.+, SJ6.1, U1.46 (VOUT0)
DSP_VOUT1: C37.+, SJ7.1, U1.45 (VOUT1)
DSP_VOUT2: C39.+, SJ8.1, U1.44 (VOUT2)
DSP_VOUT3: C41.+, SJ9.1, U1.43 (VOUT3)
GND: C16.2, C17.2, C18.2, C19.2, C20.2, C21.2, C22.2, C23.2, C24.2, C25.2, C26.2, C27.1, C28.1, C29.1, C30.1, C31.1, C32.1, C36.2, C38.2, C40.2, C42.2, R18.2, SJ1.1, U1.1 (AGND_2), U1.7 (ADDR0), U1.12 (DGND_2), U1.20 (ADDR1/CDATA/WB), U1.25 (DGND), U1.30 (RSVD), U1.33 (PGND), U1.37 (AGND_3), U1.38 (PLL_MODE0), U1.42 (AGND); also elsewhere on the board
I2C_SCL: U1.23 (SCL/CCLK); also elsewhere on the board
I2C_SDA: U1.22 (SDA/COUT); also elsewhere on the board
LINEIN_SW_L: R19.2; also elsewhere on the board
LINEIN_SW_R: R17.2; also elsewhere on the board
unnamed: R17.1, U1.2 (ADC0)
unnamed: R18.1, U1.3 (ADC_RES)
unnamed: R19.1, U1.4 (ADC1)
unnamed: C25.1, Q2.2, R20.2
unnamed: C27.2, C28.2, U1.41 (FILTD)
unnamed: C31.2, C32.2, U1.40 (CM)
unnamed: C29.2, C30.2, U1.47 (FILTA)
unnamed: C33.1, C34.1, U1.35 (PLL_LF)
unnamed: C34.2, R21.2
unnamed: C35.-, R22.2
unnamed: C37.-, R23.2
unnamed: C39.-, R24.2
unnamed: C41.-, R25.2
POT0: U1.26 (MP9); also elsewhere on the board
POT1: U1.27 (MP8); also elsewhere on the board
POT2: U1.28 (MP3); also elsewhere on the board
POT3: U1.29 (MP2); also elsewhere on the board

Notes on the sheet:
DSP
Power Supply
AVDD
PVDD
IVDD
DVDD
I2C Pull-Up resistors are on page 4
SELFBOOT Select: High -> selfboot mode Low -> I2C-control mode
Output filter

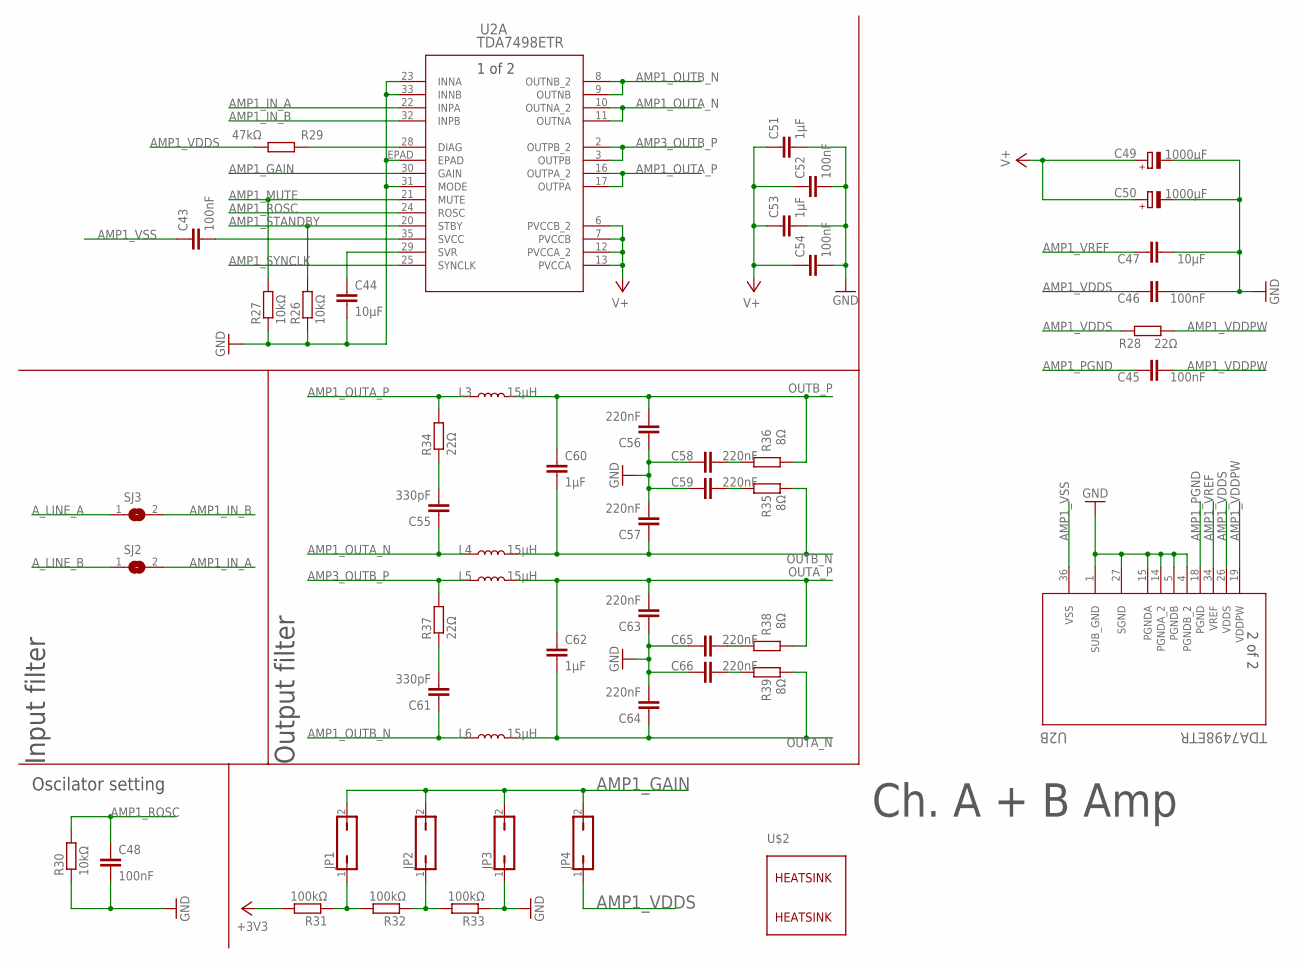
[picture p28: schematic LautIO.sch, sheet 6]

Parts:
C43, C45, C46, C48, C52, C54: 100nF; C0603
C44, C47: 10µF; C1206K
C49, C50: 1000µF; E7,5-16
C51, C53: 1µF; C0603
C55, C61: 330pF; C0603
C56, C57, C58, C59, C63, C64, C65, C66: 220nF; C0603
C60, C62: 1µF; C3640
JP1, JP2, JP3, JP4: JP1Q; JP1
L3, L4, L5, L6: 15µH; INDUCTOR_SDR1307
R26, R27, R30: 10kΩ; R0603
R28, R34, R37: 22Ω; R0603
R29: 47kΩ; R0603
R31, R32, R33: 100kΩ; R0603
R35, R36, R38, R39: 8Ω; R0603
SJ2, SJ3: SJ
U2: TDA7498ETR; SSO36_TDA7498ETR_STM
U$2: ATS-CPX030030030

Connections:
+3V3: R31.2; also elsewhere on the board
AMP1_GAIN: JP1.2, JP2.2, JP3.2, JP4.2, U2.30 (GAIN)
AMP1_IN_A: SJ2.2, U2.22 (INPA)
AMP1_IN_B: SJ3.2, U2.32 (INPB)
AMP1_MUTE: R27.2, U2.21 (MUTE); also elsewhere on the board
AMP1_OUTA_N: C55.1, L4.P$1 (1), U2.10 (OUTNA_2), U2.11 (OUTNA)
AMP1_OUTA_P: L3.P$1 (1), R34.2, U2.16 (OUTPA_2), U2.17 (OUTPA)
AMP1_OUTB_N: C61.1, L6.P$1 (1), U2.8 (OUTNB_2), U2.9 (OUTNB)
AMP1_PGND: C45.1, U2.18 (PGND)
AMP1_ROSC: C48.2, R30.2, U2.24 (ROSC)
AMP1_STANDBY: R26.2, U2.20 (STBY); also elsewhere on the board
AMP1_SYNCLK: U2.25 (SYNCLK)
AMP1_VDDPW: C45.2, R28.2, U2.19 (VDDPW)
AMP1_VDDS: C46.1, JP4.1, R28.1, R29.2, U2.26 (VDDS)
AMP1_VREF: C47.1, U2.34 (VREF)
AMP1_VSS: C43.1, U2.36 (VSS)
AMP3_OUTB_P: L5.P$1 (1), R37.2, U2.2 (OUTPB_2), U2.3 (OUTPB)
A_LINE_A: SJ3.1; also elsewhere on the board
A_LINE_B: SJ2.1; also elsewhere on the board
GND: C44.2, C46.2, C47.2, C48.1, C49.-, C50.-, C51.2, C52.2, C53.2, C54.2, C56.1, C57.2, C58.2, C59.2, C63.1, C64.2, C65.2, C66.2, JP3.1, R26.1, R27.1, R30.1, R33.1, U2.1 (SUB_GND), U2.4 (PGNDB_2), U2.5 (PGNDB), U2.14 (PGNDA_2), U2.15 (PGNDA), U2.23 (INNA), U2.27 (SGND), U2.31 (MODE), U2.33 (INNB), U2.EPAD; also elsewhere on the board
unnamed: C43.2, U2.35 (SVCC)
unnamed: C44.1, U2.29 (SVR)
unnamed: R29.1, U2.28 (DIAG)
unnamed: JP1.1, R31.1, R32.2
unnamed: JP2.1, R32.1, R33.2
unnamed: C55.2, R34.1
unnamed: C59.1, R35.2
unnamed: C58.1, R36.2
unnamed: C61.2, R37.1
unnamed: C65.1, R38.2
unnamed: C66.1, R39.2
OUTA_N: C62.2, C64.1, L6.P$2 (2), R39.1; also elsewhere on the board
OUTA_P: C62.1, C63.2, L5.P$2 (2), R38.1; also elsewhere on the board
OUTB_N: C57.1, C60.2, L4.P$2 (2), R35.1; also elsewhere on the board
OUTB_P: C56.2, C60.1, L3.P$2 (2), R36.1; also elsewhere on the board
V+: C49.+, C50.+, C51.1, C52.1, C53.1, C54.1, U2.6 (PVCCB_2), U2.7 (PVCCB), U2.12 (PVCCA_2), U2.13 (PVCCA); also elsewhere on the board

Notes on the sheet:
Ch. A + B Amp
Oscilator setting
Input filter
Output filter

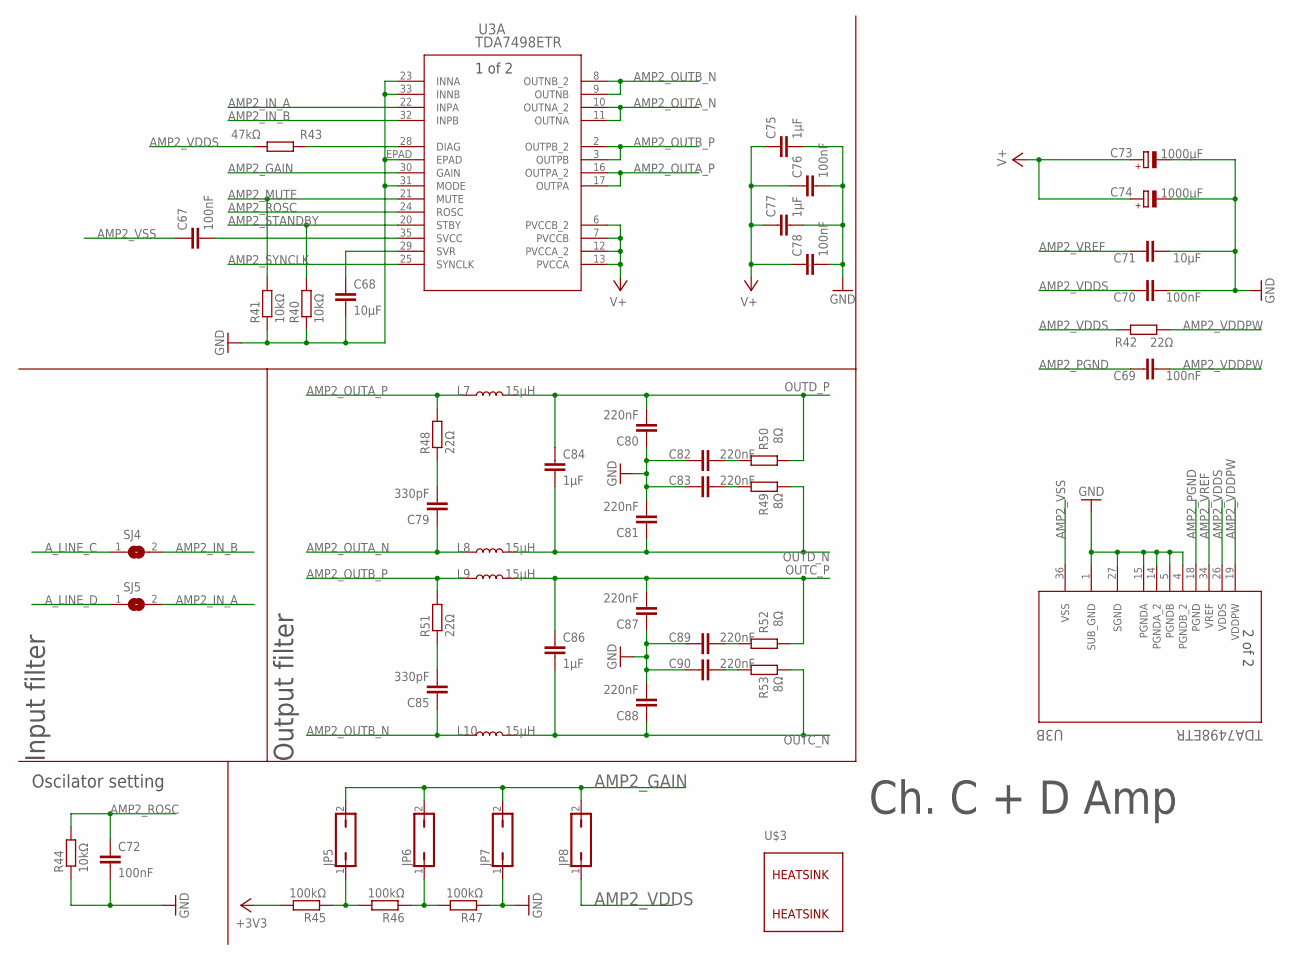
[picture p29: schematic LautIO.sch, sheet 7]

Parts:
C67, C69, C70, C72, C76, C78: 100nF; C0603
C68, C71: 10µF; C1206K
C73, C74: 1000µF; E7,5-16
C75, C77: 1µF; C0603
C79, C85: 330pF; C0603
C80, C81, C82, C83, C87, C88, C89, C90: 220nF; C0603
C84, C86: 1µF; C3640
JP5, JP6, JP7, JP8: JP1Q; JP1
L7, L8, L9, L10: 15µH; INDUCTOR_SDR1307
R40, R41, R44: 10kΩ; R0603
R42, R48, R51: 22Ω; R0603
R43: 47kΩ; R0603
R45, R46, R47: 100kΩ; R0603
R49, R50, R52, R53: 8Ω; R0603
SJ4, SJ5: SJ
U3: TDA7498ETR; SSO36_TDA7498ETR_STM
U$3: ATS-CPX030030030

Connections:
+3V3: R45.2; also elsewhere on the board
AMP2_GAIN: JP5.2, JP6.2, JP7.2, JP8.2, U3.30 (GAIN)
AMP2_IN_A: SJ5.2, U3.22 (INPA)
AMP2_IN_B: SJ4.2, U3.32 (INPB)
AMP2_MUTE: R41.2, U3.21 (MUTE); also elsewhere on the board
AMP2_OUTA_N: C79.1, L8.P$1 (1), U3.10 (OUTNA_2), U3.11 (OUTNA)
AMP2_OUTA_P: L7.P$1 (1), R48.2, U3.16 (OUTPA_2), U3.17 (OUTPA)
AMP2_OUTB_N: C85.1, L10.P$1 (1), U3.8 (OUTNB_2), U3.9 (OUTNB)
AMP2_OUTB_P: L9.P$1 (1), R51.2, U3.2 (OUTPB_2), U3.3 (OUTPB)
AMP2_PGND: C69.1, U3.18 (PGND)
AMP2_ROSC: C72.2, R44.2, U3.24 (ROSC)
AMP2_STANDBY: R40.2, U3.20 (STBY); also elsewhere on the board
AMP2_SYNCLK: U3.25 (SYNCLK)
AMP2_VDDPW: C69.2, R42.2, U3.19 (VDDPW)
AMP2_VDDS: C70.1, JP8.1, R42.1, R43.2, U3.26 (VDDS)
AMP2_VREF: C71.1, U3.34 (VREF)
AMP2_VSS: C67.1, U3.36 (VSS)
A_LINE_C: SJ4.1; also elsewhere on the board
A_LINE_D: SJ5.1; also elsewhere on the board
GND: C68.2, C70.2, C71.2, C72.1, C73.-, C74.-, C75.2, C76.2, C77.2, C78.2, C80.1, C81.2, C82.2, C83.2, C87.1, C88.2, C89.2, C90.2, JP7.1, R40.1, R41.1, R44.1, R47.1, U3.1 (SUB_GND), U3.4 (PGNDB_2), U3.5 (PGNDB), U3.14 (PGNDA_2), U3.15 (PGNDA), U3.23 (INNA), U3.27 (SGND), U3.31 (MODE), U3.33 (INNB), U3.EPAD; also elsewhere on the board
unnamed: C67.2, U3.35 (SVCC)
unnamed: C68.1, U3.29 (SVR)
unnamed: R43.1, U3.28 (DIAG)
unnamed: JP5.1, R45.1, R46.2
unnamed: JP6.1, R46.1, R47.2
unnamed: C79.2, R48.1
unnamed: C83.1, R49.2
unnamed: C82.1, R50.2
unnamed: C85.2, R51.1
unnamed: C89.1, R52.2
unnamed: C90.1, R53.2
OUTC_N: C86.2, C88.1, L10.P$2 (2), R53.1; also elsewhere on the board
OUTC_P: C86.1, C87.2, L9.P$2 (2), R52.1; also elsewhere on the board
OUTD_N: C81.1, C84.2, L8.P$2 (2), R49.1; also elsewhere on the board
OUTD_P: C80.2, C84.1, L7.P$2 (2), R50.1; also elsewhere on the board
V+: C73.+, C74.+, C75.1, C76.1, C77.1, C78.1, U3.6 (PVCCB_2), U3.7 (PVCCB), U3.12 (PVCCA_2), U3.13 (PVCCA); also elsewhere on the board

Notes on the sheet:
Ch. C + D Amp
Oscilator setting
Input filter
Output filter

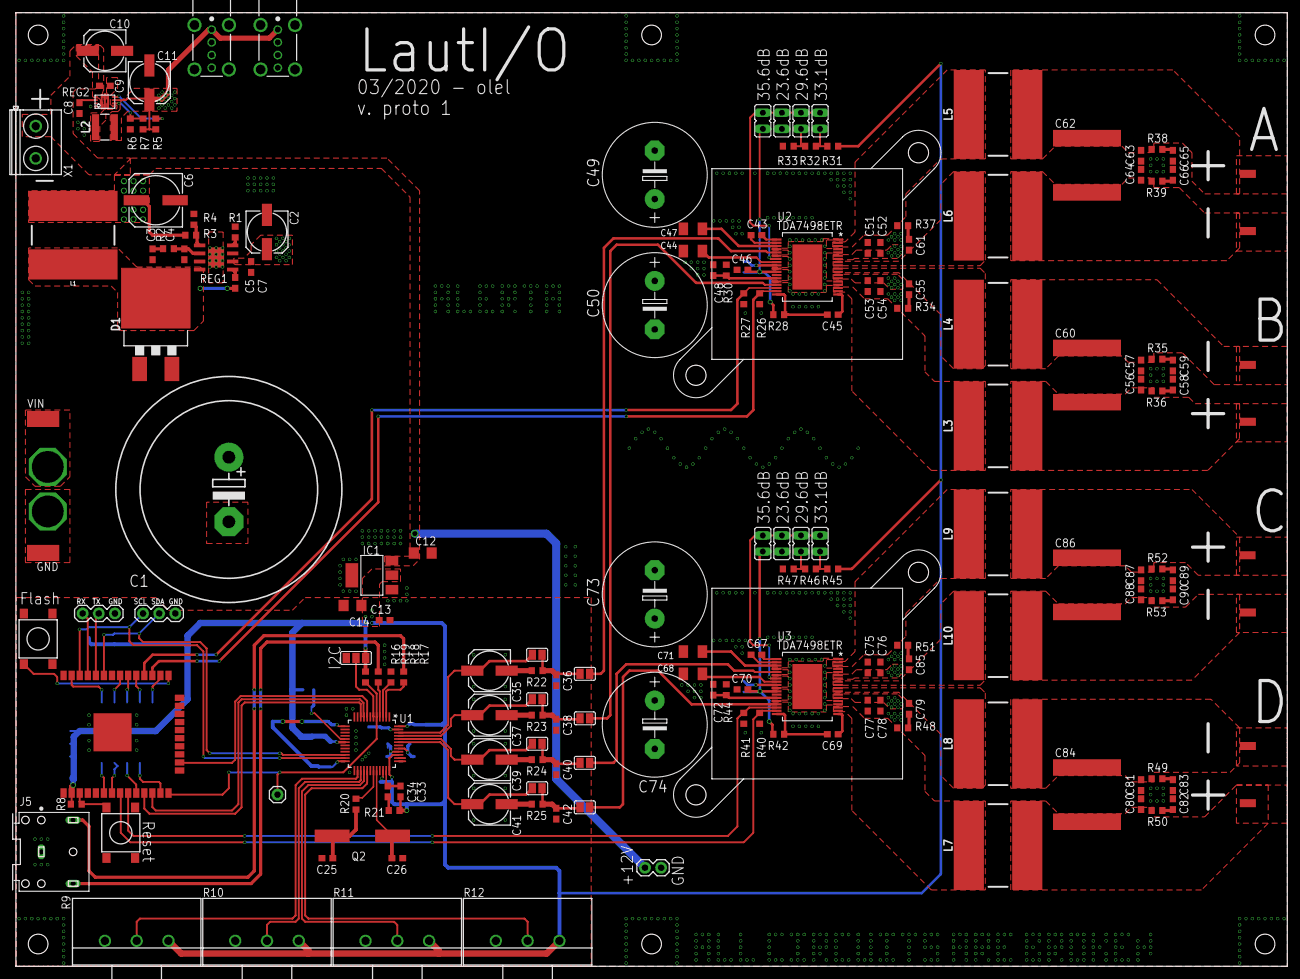
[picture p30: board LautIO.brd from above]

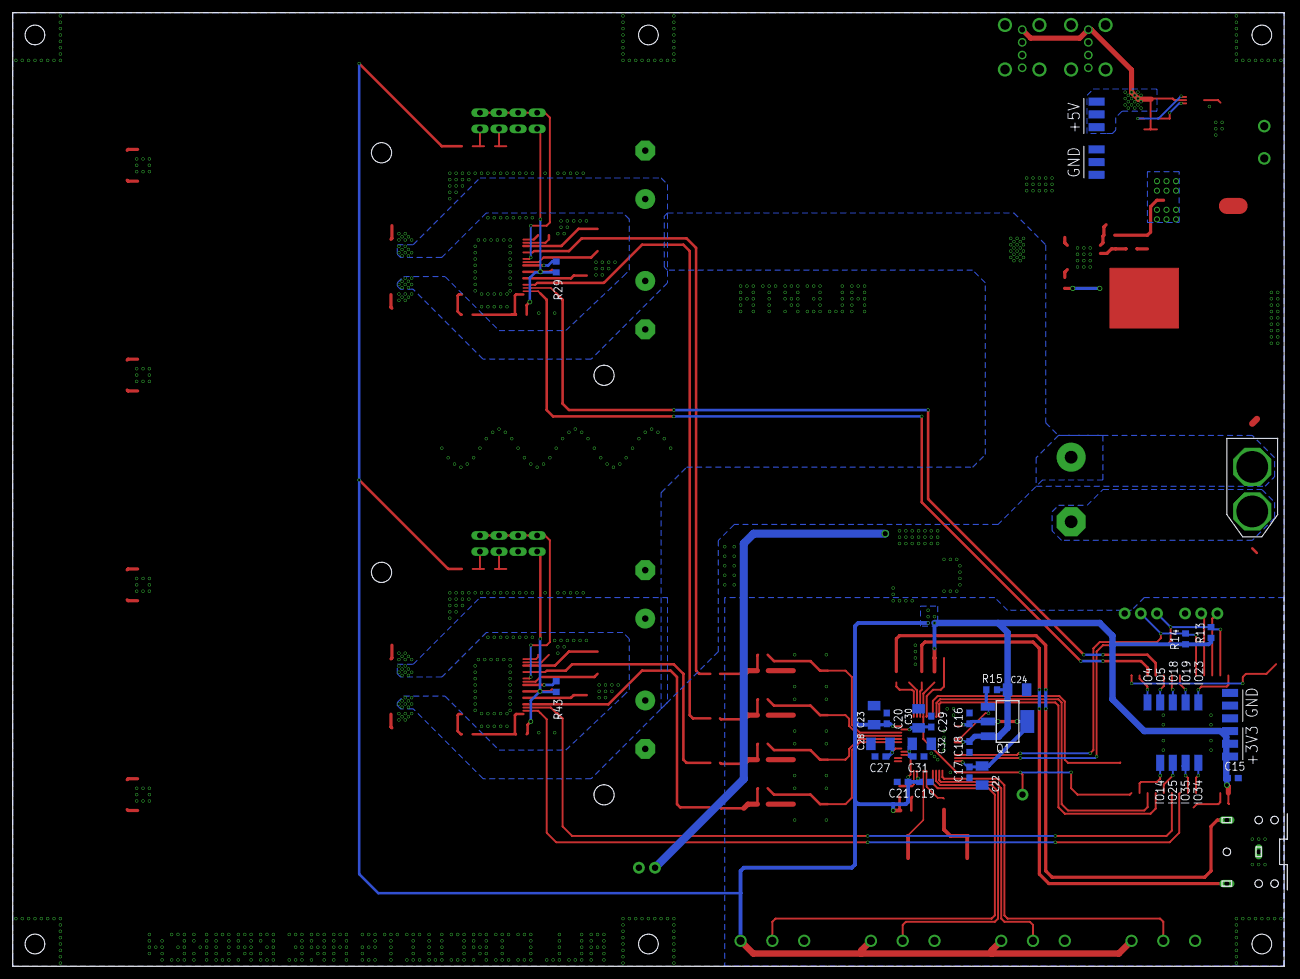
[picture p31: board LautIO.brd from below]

Board: 2 copper layers, 200.0 x 150.0 mm, 224 parts (44 on the bottom side), 126 nets.

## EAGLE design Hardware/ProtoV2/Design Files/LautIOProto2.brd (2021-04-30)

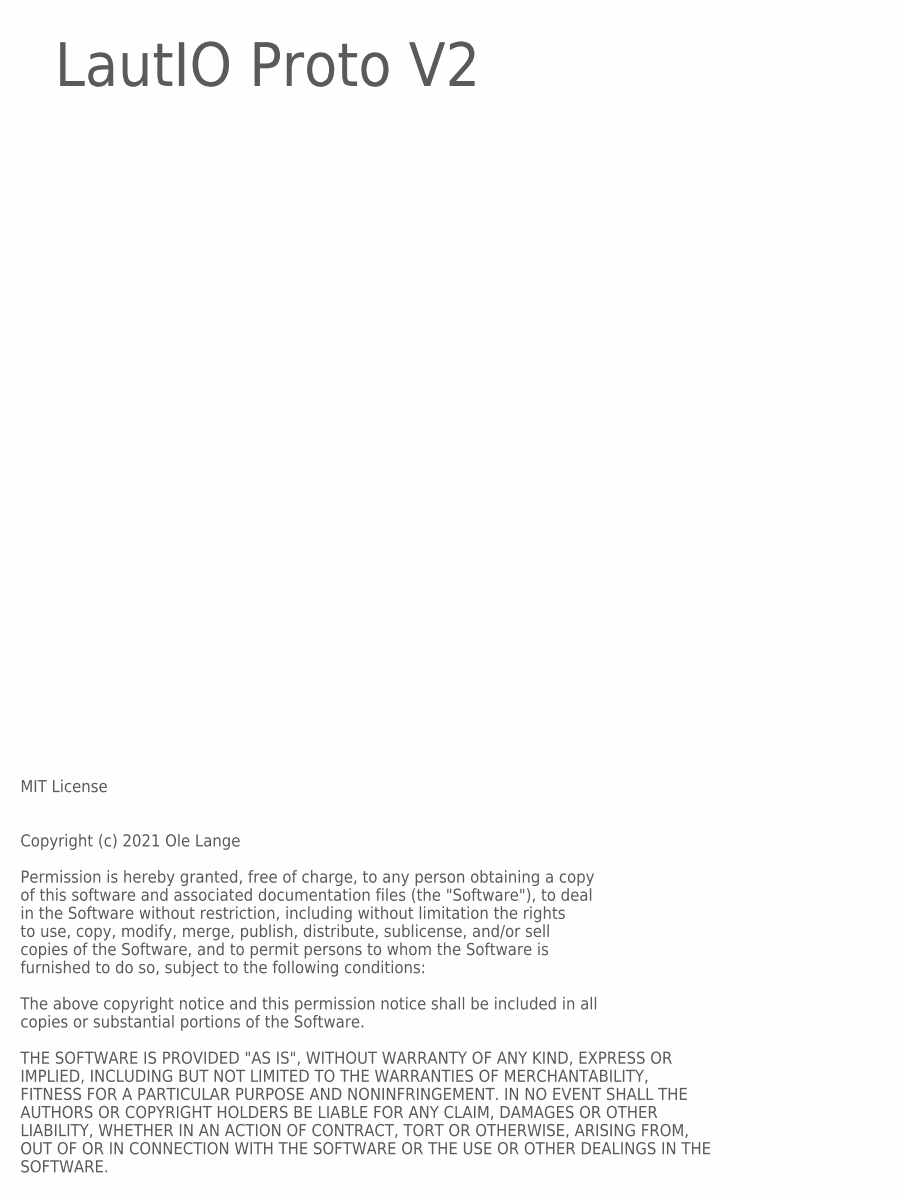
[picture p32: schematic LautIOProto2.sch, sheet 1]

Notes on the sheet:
LautIO Proto V2
MIT License Copyright (c) 2021 Ole Lange Permission is hereby granted, free of charge, to any person obtaining a copy of this software and associated documentation files (the "Software"), to deal in the Software without restriction, including without limitation the rights to use, copy, modify, merg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

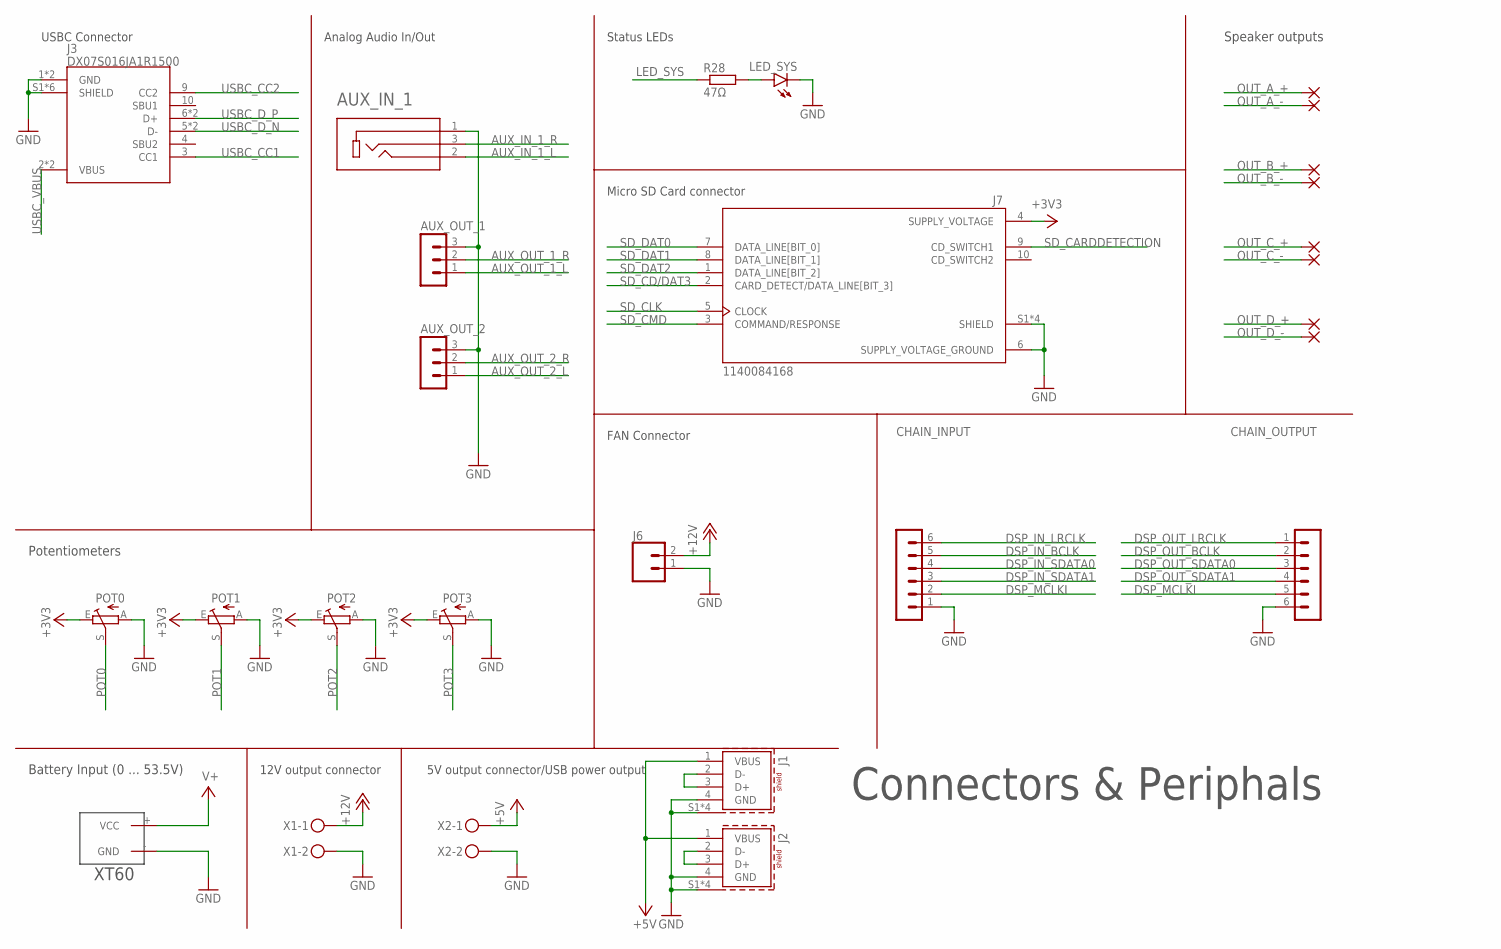
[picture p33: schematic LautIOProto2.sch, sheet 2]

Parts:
AUX_IN_1: SJ1-3523N; CUI_SJ1-3523N
AUX_OUT_1, AUX_OUT_2: MA03-1
CHAIN_INPUT: MA06-1
CHAIN_OUTPUT: MA06-1
J1, J2: 614004134726
J3: DX07S016JA1R1500; JAE_DX07S016JA1R1500
J6: CONN_02PTH3; 1X02_LONGPADS
J7: 1140084168; AMPHENOL_1140084168
LED_SYS: LEDSML0603; SML0603
PAD1, PAD2, PAD3, PAD4, PAD5, PAD6, PAD7, PAD8: SMD2; SMD1,27-2,54
POT0, POT1, POT2, POT3: TRIM_EU-CIP20C-6MM; CIP20C-6MM
R28: 47Ω; R0603
U$1: XT60
X1, X2: MKDSN1,5/2-5,08

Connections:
+3V3: J7.4 (SUPPLY_VOLTAGE), POT0.E, POT1.E, POT2.E, POT3.E; also elsewhere on the board
+5V: J1.1 (VBUS), J2.1 (VBUS), X2.1; also elsewhere on the board
+12V: J6.2, X1.1; also elsewhere on the board
AUX_IN_1_L: AUX_IN_1.2; also elsewhere on the board
AUX_IN_1_R: AUX_IN_1.3; also elsewhere on the board
AUX_OUT_1_L: AUX_OUT_1.1; also elsewhere on the board
AUX_OUT_1_R: AUX_OUT_1.2; also elsewhere on the board
AUX_OUT_2_L: AUX_OUT_2.1; also elsewhere on the board
AUX_OUT_2_R: AUX_OUT_2.2; also elsewhere on the board
DSP_IN_BCLK: CHAIN_INPUT.5; also elsewhere on the board
DSP_IN_LRCLK: CHAIN_INPUT.6; also elsewhere on the board
DSP_IN_SDATA0: CHAIN_INPUT.4; also elsewhere on the board
DSP_IN_SDATA1: CHAIN_INPUT.3; also elsewhere on the board
DSP_MCLKI: CHAIN_INPUT.2, CHAIN_OUTPUT.5; also elsewhere on the board
DSP_OUT_BCLK: CHAIN_OUTPUT.2; also elsewhere on the board
DSP_OUT_LRCLK: CHAIN_OUTPUT.1; also elsewhere on the board
DSP_OUT_SDATA0: CHAIN_OUTPUT.3; also elsewhere on the board
DSP_OUT_SDATA1: CHAIN_OUTPUT.4; also elsewhere on the board
GND: AUX_IN_1.1, AUX_OUT_1.3, AUX_OUT_2.3, CHAIN_INPUT.1, CHAIN_OUTPUT.6, J1.4 (GND), J1.S1 (SHIELD), J1.S2 (SHIELD), J1.S3 (SHIELD), J1.S4 (SHIELD), J2.4 (GND), J2.S1 (SHIELD), J2.S2 (SHIELD), J2.S3 (SHIELD), J2.S4 (SHIELD), J3.1 (GND), J3.12 (GND), J3.S1 (SHIELD), J3.S2 (SHIELD), J3.S3 (SHIELD), J3.S4 (SHIELD), J3.S5 (SHIELD), J3.S6 (SHIELD), J6.1, J7.6 (SUPPLY_VOLTAGE_GROUND), J7.S1 (SHIELD), J7.S2 (SHIELD), J7.S3 (SHIELD), J7.S4 (SHIELD), LED_SYS.C, POT0.A, POT1.A, POT2.A, POT3.A, U$1.- (GND), X1.2, X2.2; also elsewhere on the board
LED_SYS: R28.1; also elsewhere on the board
unnamed: J2.2 (D-), J2.3 (D+)
unnamed: J1.2 (D-), J1.3 (D+)
unnamed: LED_SYS.A, R28.2
OUT_A_+: PAD1.1; also elsewhere on the board
OUT_A_-: PAD2.1; also elsewhere on the board
OUT_B_+: PAD4.1; also elsewhere on the board
OUT_B_-: PAD3.1; also elsewhere on the board
OUT_C_+: PAD5.1; also elsewhere on the board
OUT_C_-: PAD6.1; also elsewhere on the board
OUT_D_+: PAD8.1; also elsewhere on the board
OUT_D_-: PAD7.1; also elsewhere on the board
POT0: POT0.S; also elsewhere on the board
POT1: POT1.S; also elsewhere on the board
POT2: POT2.S; also elsewhere on the board
POT3: POT3.S; also elsewhere on the board
SD_CARDDETECTION: J7.9 (CD_SWITCH1); also elsewhere on the board
SD_CD/DAT3: J7.2 (CARD_DETECT/DATA_LINE[BIT_3]); also elsewhere on the board
SD_CLK: J7.5 (CLOCK); also elsewhere on the board
SD_CMD: J7.3 (COMMAND/RESPONSE); also elsewhere on the board
SD_DAT0: J7.7 (DATA_LINE[BIT_0]); also elsewhere on the board
SD_DAT1: J7.8 (DATA_LINE[BIT_1]); also elsewhere on the board
SD_DAT2: J7.1 (DATA_LINE[BIT_2]); also elsewhere on the board
USBC_CC1: J3.3 (CC1); also elsewhere on the board
USBC_CC2: J3.9 (CC2); also elsewhere on the board
USBC_D_N: J3.5 (D-), J3.8 (D-); also elsewhere on the board
USBC_D_P: J3.6 (D+), J3.7 (D+); also elsewhere on the board
USBC_VBUS: J3.2 (VBUS), J3.11 (VBUS); also elsewhere on the board
V+: U$1.+ (VCC); also elsewhere on the board

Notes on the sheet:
Battery Input (0 ... 53.5V)
12V output connector
Connectors & Periphals
5V output connector/USB power output
Potentiometers
Speaker outputs
USBC Connector
Micro SD Card connector
Analog Audio In/Out
Status LEDs
FAN Connector

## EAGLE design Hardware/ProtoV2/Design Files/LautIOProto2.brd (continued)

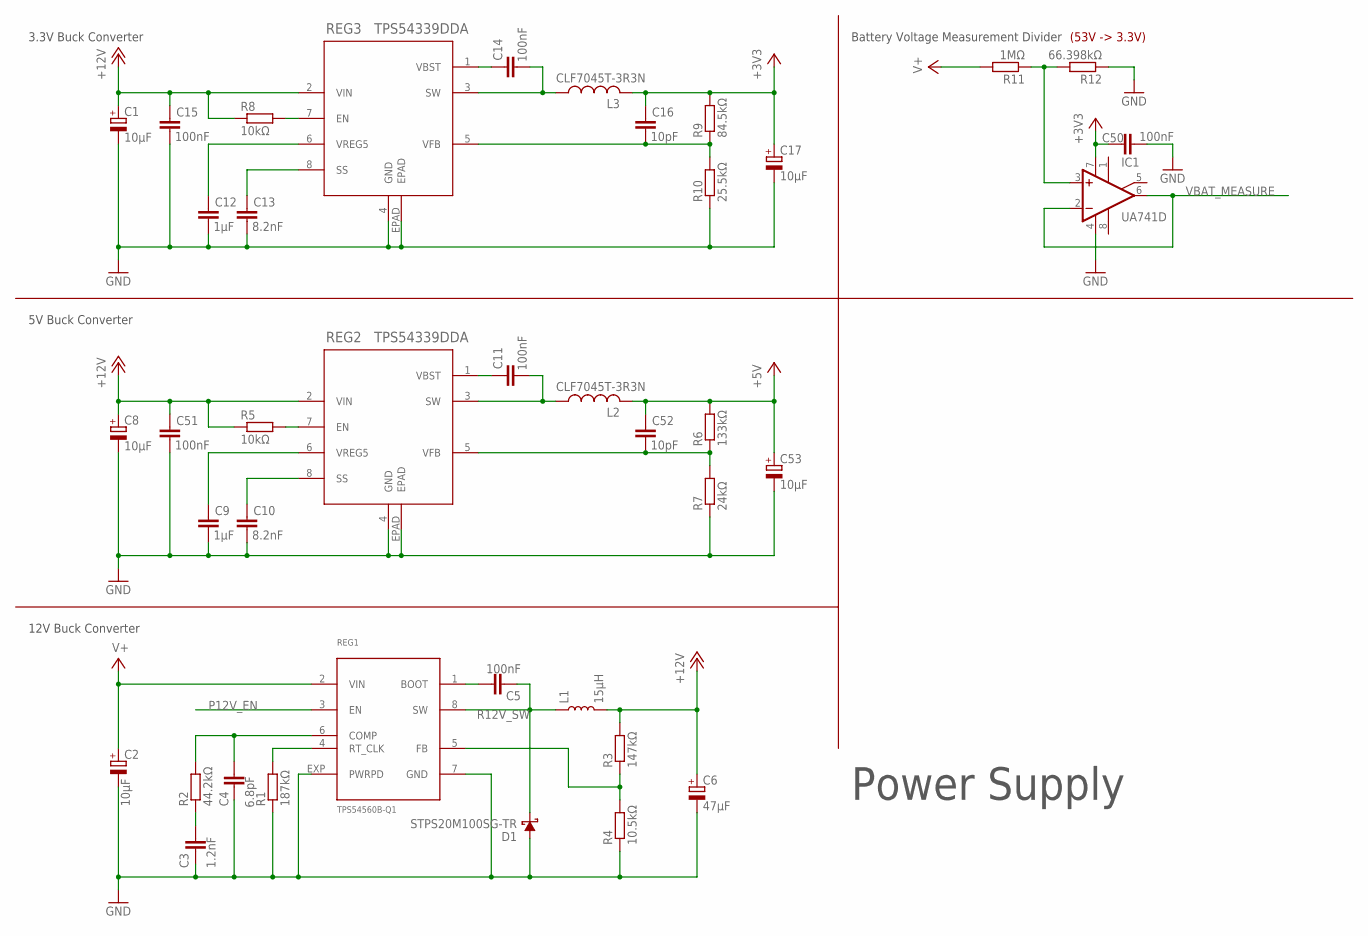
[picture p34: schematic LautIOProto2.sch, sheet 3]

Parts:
C1, C2, C8, C17, C53: 10µF; 153CLV-0605
C3: 1.2nF; C0603
C4: 6.8pF; C0603
C5, C11, C14, C15, C50, C51: 100nF; C0603
C6: 47µF; 153CLV-0807
C9, C12: 1µF; C3216
C10, C13: 8.2nF; C0603
C16, C52: 10pF; C0603
D1: STPS20M100SG-TR; TO-263/D2PAK
IC1: UA741D; SO08
L1: 15µH; INDUCTOR_SDR1307
L2, L3: CLF7045T-3R3N; L5650M
R1: 187kΩ; R0603
R2: 44.2kΩ; R0603
R3: 147kΩ; R0603
R4: 10.5kΩ; R0603
R5, R8: 10kΩ; R0603
R6: 133kΩ; R0603
R7: 24kΩ; R0603
R9: 84.5kΩ; R0603
R10: 25.5kΩ; R0603
R11: 1MΩ; R0603
R12: 66.398kΩ; R0603
REG1: TPS54560B-Q1; HSOP8
REG2, REG3: TPS54339DDA; DDA8_3P1X2P4_TEX

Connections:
+3V3: C16.1, C17.+, C50.1, IC1.7 (V+), L3.2, R9.2; also elsewhere on the board
+5V: C52.1, C53.+, L2.2, R6.2; also elsewhere on the board
+12V: C1.+, C6.+, C8.+, C15.1, C51.1, L1.P$2 (2), R3.2, R5.1, R8.1, REG2.2 (VIN), REG3.2 (VIN); also elsewhere on the board
GND: C1.-, C2.-, C3.2, C4.2, C6.-, C8.-, C9.2, C10.2, C12.2, C13.2, C15.2, C17.-, C50.2, C51.2, C53.-, D1.1 (A), D1.3 (A), IC1.4 (V-), R1.1, R4.1, R7.1, R10.1, R12.1, REG1.7 (GND), REG1.EXP (PWRPD), REG2.4 (GND), REG2.EPAD, REG3.4 (GND), REG3.EPAD; also elsewhere on the board
unnamed: R1.2, REG1.4 (RT_CLK)
unnamed: C4.1, R2.2, REG1.6 (COMP)
unnamed: C3.1, R2.1
unnamed: C5.1, REG1.1 (BOOT)
unnamed: R3.1, R4.2, REG1.5 (FB)
unnamed: R5.2, REG2.7 (EN)
unnamed: C10.1, REG2.8 (SS)
unnamed: C9.1, REG2.6 (VREG5)
unnamed: C11.1, REG2.1 (VBST)
unnamed: R8.2, REG3.7 (EN)
unnamed: C14.1, REG3.1 (VBST)
unnamed: C13.1, REG3.8 (SS)
unnamed: C12.1, REG3.6 (VREG5)
unnamed: C14.2, L3.1, REG3.3 (SW)
unnamed: C16.2, R9.1, R10.2, REG3.5 (VFB)
unnamed: IC1.3 (+IN), R11.1, R12.2
unnamed: C11.2, L2.1, REG2.3 (SW)
unnamed: C52.2, R6.1, R7.2, REG2.5 (VFB)
P12V_EN: REG1.3 (EN)
R12V_SW: C5.2, D1.2 (C), L1.P$1 (1), REG1.8 (SW)
V+: C2.+, R11.2, REG1.2 (VIN); also elsewhere on the board
VBAT_MEASURE: IC1.2 (-IN), IC1.6 (OUT); also elsewhere on the board

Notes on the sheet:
Power Supply
12V Buck Converter
5V Buck Converter
3.3V Buck Converter
Battery Voltage Measurement Divider
(53V -> 3.3V)


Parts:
3V3IO: SMD2; SMD1,27-2,54
C18, C19, C20, C49: 100nF; C0603
IC6: CP2102; MLP28
IO1, IO2, IO3, IO4, IO5, IO26, IO27, IO32, IO33, IO34: SMD2; SMD1,27-2,54
J4, J5: 455-1750-1-ND; 1X03
Q1, Q2: SS8050-G; SOT23-BEC
R13, R16, R17: 10kΩ; R0603
R14, R15: 4.7kΩ; R0603
R18, R19: 5.1kΩ; R0603
R20: 22.1kΩ; R0603
R21: 47.5kΩ; R0603
R22: 2kΩ; R0603
R44: 0kΩ; R0603
R45, R46, R47, R48, R49: 47kΩ; R0603
S1, S2: MOMENTARY-SWITCH-SPST-SMD-6.2MM-TALL; TACTILE_SWITCH_SMD_6.2MM_TALL
U1: ESP-WROOM-32
VD1: USBLC6-2SC6; SOT-23-6L

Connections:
+3V3: 3V3IO.1, C18.1, C19.1, C20.1, C49.1, IC6.6 (VDD), IC6.7 (REGIN), IO2.1, IO3.1, R13.2, R14.1, R15.1, R22.1, R45.1, R46.1, R47.1, R48.1, R49.1, U1.2 (3V3); also elsewhere on the board
AMP1_CLIP_OTW: U1.29 (IO5); also elsewhere on the board
AMP1_FAULT: U1.30 (IO18); also elsewhere on the board
AMP2_CLIP_OTW: U1.31 (IO19); also elsewhere on the board
AMP2_FAULT: U1.37 (IO23); also elsewhere on the board
CP2102_D_N: IC6.5 (D-), VD1.4 (I/O2)
CP2102_D_P: IC6.4 (D+), VD1.6 (I/O1)
DSP_RESET: U1.10 (IO25); also elsewhere on the board
ESP_EN: Q1.C, R13.1, S1.A2 (1), U1.3 (EN)
ESP_IO0: Q2.C, S2.A2 (1), U1.25 (IO0)
ESP_IO26: IO26.1, U1.11 (IO26)
ESP_IO27: IO27.1, U1.12 (IO27)
ESP_IO32: IO32.1, U1.8 (IO32)
ESP_IO33: IO33.1, U1.9 (IO33)
ESP_IO34: IO34.1, U1.6 (IO34)
ESP_RXD0: IC6.26 (TXD), J4.2, U1.34 (RXD0)
ESP_TXD0: IC6.25 (RXD), J4.1, U1.35 (TXD0)
GND: C18.2, C19.2, C20.2, C49.2, IC6.3 (GND), IC6.EXP (GND), IC6.M (GND), IO1.1, IO4.1, IO5.1, J4.3, J5.3, R18.2, R19.2, R21.2, S1.B2 (2), S2.B2 (2), U1.1 (GND), U1.15 (GND), U1.38 (GND), U1.GND, VD1.2 (GND); also elsewhere on the board
I2C_SCL: J5.1, R14.2, U1.36 (IO22); also elsewhere on the board
I2C_SDA: J5.2, R15.2, U1.33 (IO21); also elsewhere on the board
LED_SYS: U1.28 (IO17); also elsewhere on the board
unnamed: Q1.B, R16.2
unnamed: R44.2, U1.7 (IO35)
unnamed: Q2.B, R17.2
unnamed: IC6.8 (VBUS), R20.2, R21.1
unnamed: IC6.9 (!RST), R22.2
SD_CARDDETECTION: U1.27 (IO16); also elsewhere on the board
SD_CD/DAT3: R46.2, U1.16 (IO13); also elsewhere on the board
SD_CLK: U1.13 (IO14); also elsewhere on the board
SD_CMD: R47.2, U1.23 (IO15); also elsewhere on the board
SD_DAT0: R48.2, U1.24 (IO2); also elsewhere on the board
SD_DAT1: R49.2, U1.26 (IO4); also elsewhere on the board
SD_DAT2: R45.2, U1.14 (IO12); also elsewhere on the board
SER_DTR: IC6.28 (DTR), Q2.E, R16.1
SER_RTS: IC6.24 (RTS), Q1.E, R17.1
USBC_CC1: R18.1; also elsewhere on the board
USBC_CC2: R19.1; also elsewhere on the board
USBC_D_N: VD1.3 (I/O_2); also elsewhere on the board
USBC_D_P: VD1.1 (I/O_1); also elsewhere on the board
USBC_VBUS: R20.1, VD1.5 (VBUS); also elsewhere on the board
VBAT_MEASURE: R44.1; also elsewhere on the board

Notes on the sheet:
ESP32 + USB UART
Reset-/Flash Button
Bypass Caps
ESP32-WROOM-32 Module
esp32 Serial/Flash Port
i2c resistors/port
Auto programming circuit
USBC Stuff
ESP32
CP2102
USB <-> UART Converter
USB ESD Protection
NC!
SD Card Peripherals


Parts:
C22, C23, C24, C25, C26, C27, C33, C35, C37: 100n; C0603
C28, C29, C30, C34, C36: 10µF; C1206K
C31, C32: 22pF; C0603
C38: 47µF; C1206K
C39: 3.3nF; C0603
C40: 56nF; C0603
C41, C43, C45, C47: 47µF; 153CLV-0605
C42, C44, C46, C48: 5.6nF; C0603
Q3: ZX5T953; SOT223
Q4: 12.288MHz; CSM-7X-DU
R29: 1kΩ; R0603
R30: 10kΩ; R0603
R31, R32, R33: 18kΩ; R0603
R34: 100Ω; R0603
R35: 475Ω; R0603
R36, R37, R38, R39: 560Ω; R0603
R40, R41, R42, R43: 0Ω; R0603
SJ1: SJ2W; SJ_2
SJ2, SJ6, SJ7, SJ8, SJ9: SJ
U3: ADAU1701JSTZ; ST_48_ADI

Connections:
+3V3: C24.1, C25.1, C26.1, C27.1, C29.1, C30.1, C39.2, Q3.3 (E), R29.2, R30.2, R35.1, SJ1.3, U3.18 (IOVDD), U3.34 (PVDD), U3.36 (AVDD_2), U3.39 (PLL_MODE1), U3.48 (AVDD); also elsewhere on the board
AUX_IN_1_L: R33.2; also elsewhere on the board
AUX_IN_1_R: R31.2; also elsewhere on the board
AUX_OUT_1_L: R41.2; also elsewhere on the board
AUX_OUT_1_R: R40.2; also elsewhere on the board
AUX_OUT_2_L: R43.2; also elsewhere on the board
AUX_OUT_2_R: R42.2; also elsewhere on the board
A_LINE_A: C42.1, R36.1, R40.1, SJ6.2; also elsewhere on the board
A_LINE_B: C44.1, R37.1, R41.1, SJ7.2; also elsewhere on the board
A_LINE_C: C46.1, R38.1, R42.1, SJ8.2; also elsewhere on the board
A_LINE_D: C48.1, R39.1, R43.1, SJ9.2; also elsewhere on the board
CRYSTAL_MCLKI: C32.1, Q4.1, SJ2.1
DSP_DVDD: C22.1, C23.1, C28.1, Q3.2 (C), Q3.4 (C), U3.13 (DVDD_2), U3.24 (DVDD)
DSP_IN_BCLK: U3.9 (MP5); also elsewhere on the board
DSP_IN_LRCLK: U3.8 (MP4); also elsewhere on the board
DSP_IN_SDATA0: U3.10 (MP1); also elsewhere on the board
DSP_IN_SDATA1: U3.11 (MP0); also elsewhere on the board
DSP_MCLKI: SJ2.2, U3.32 (MCLKI); also elsewhere on the board
DSP_OSCO: R34.1, U3.31 (OSCO)
DSP_OUT_BCLK: U3.19 (MP11); also elsewhere on the board
DSP_OUT_LRCLK: U3.16 (MP10); also elsewhere on the board
DSP_OUT_SDATA0: U3.15 (MP6); also elsewhere on the board
DSP_OUT_SDATA1: U3.14 (MP7); also elsewhere on the board
DSP_RESET: R30.1, U3.5 (!RESET); also elsewhere on the board
DSP_SELFBOOT: SJ1.2, U3.6 (SELFBOOT)
DSP_VDRIVE: Q3.1 (B), R29.1, U3.17 (VDRIVE)
DSP_VOUT0: C41.+, SJ6.1, U3.46 (VOUT0)
DSP_VOUT1: C43.+, SJ7.1, U3.45 (VOUT1)
DSP_VOUT2: C45.+, SJ8.1, U3.44 (VOUT2)
DSP_VOUT3: C47.+, SJ9.1, U3.43 (VOUT3)
GND: C22.2, C23.2, C24.2, C25.2, C26.2, C27.2, C28.2, C29.2, C30.2, C31.2, C32.2, C33.1, C34.1, C35.1, C36.1, C37.1, C38.1, C42.2, C44.2, C46.2, C48.2, R32.2, SJ1.1, U3.1 (AGND_2), U3.7 (ADDR0), U3.12 (DGND_2), U3.20 (ADDR1/CDATA/WB), U3.25 (DGND), U3.30 (RSVD), U3.33 (PGND), U3.37 (AGND_3), U3.38 (PLL_MODE0), U3.42 (AGND); also elsewhere on the board
I2C_SCL: U3.23 (SCL/CCLK); also elsewhere on the board
I2C_SDA: U3.22 (SDA/COUT); also elsewhere on the board
unnamed: R31.1, U3.2 (ADC0)
unnamed: R32.1, U3.3 (ADC_RES)
unnamed: R33.1, U3.4 (ADC1)
unnamed: C31.1, Q4.2, R34.2
unnamed: C33.2, C34.2, U3.41 (FILTD)
unnamed: C35.2, C36.2, U3.47 (FILTA)
unnamed: C37.2, C38.2, U3.40 (CM)
unnamed: C39.1, C40.1, U3.35 (PLL_LF)
unnamed: C40.2, R35.2
unnamed: C41.-, R36.2
unnamed: C43.-, R37.2
unnamed: C45.-, R38.2
unnamed: C47.-, R39.2
POT0: U3.26 (MP9); also elsewhere on the board
POT1: U3.27 (MP8); also elsewhere on the board
POT2: U3.28 (MP3); also elsewhere on the board
POT3: U3.29 (MP2); also elsewhere on the board

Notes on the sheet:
DSP
DSP Power Supply
AVDD
PVDD
IVDD
DVDD
I2C Pull-Up resistors are on page 4
SELFBOOT Select: High -> selfboot mode Low -> I2C-control mode
Output filter
Line Out Jumper
ADAU1701 DSP
Leader/Follower select


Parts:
AMP1: TPA3255-Q1; HTSSOP44
C7: 47nF; C0603
C54, C55, C56, C57, C58, C61, C62, C66, C67, C69, C83: 1µF; C3216
C59, C60: 4700µF; EB22,5D
C63, C64, C65, C68, C70, C75, C76, C81, C82, C84: 100nF; C0603
C71, C72, C77, C78: 22pF; C0603
C73, C74, C79, C80: 10µF; C3216
IC2, IC3: NE5532D; SO08
L4, L5: 10µH; L2012C
R50: 30kΩ; R0603
R51: 22kΩ; R0603
R52, R55, R56, R57, R58, R62, R63, R64, R65, R69, R70: 10kΩ; R0603
R53, R54: 0Ω; R0603
R59, R66: 100kΩ; R0603
R60, R61, R67, R68: 100Ω; R0603

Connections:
+3V3: R52.1; also elsewhere on the board
+12V: L4.1, L5.1, R53.1, R54.1; also elsewhere on the board
+12VOA: C66.1, C67.1, C68.1, C69.1, C70.1, IC2.8 (V+), IC3.8 (V+), L5.2, R69.1
AMP1_BST_A: AMP1.P$44 (BST_A); also elsewhere on the board
AMP1_BST_B: AMP1.P$43 (BST_B); also elsewhere on the board
AMP1_BST_C: AMP1.P$24 (BST_C); also elsewhere on the board
AMP1_BST_D: AMP1.P$23 (BST_D); also elsewhere on the board
AMP1_CLIP_OTW: AMP1.P$21 (!CLIP_OTW); also elsewhere on the board
AMP1_FAULT: AMP1.P$19 (!FAULT); also elsewhere on the board
AMP1_IN_A: AMP1.P$5 (INPUT_A), C76.2, R61.2
AMP1_IN_B: AMP1.P$6 (INPUT_B), C75.2, R60.2
AMP1_IN_C: AMP1.P$16 (INPUT_C), C82.2, R68.2
AMP1_IN_D: AMP1.P$17 (INPUT_D), C81.2, R67.2
AMP1_PWM_A: AMP1.P$39 (OUT_A), AMP1.P$40 (OUT_A); also elsewhere on the board
AMP1_PWM_B: AMP1.P$35 (OUT_B); also elsewhere on the board
AMP1_PWM_C: AMP1.P$32 (OUT_C); also elsewhere on the board
AMP1_PWM_D: AMP1.P$27 (OUT_D), AMP1.P$28 (OUT_D); also elsewhere on the board
A_LINE_A: R58.1, R59.2; also elsewhere on the board
A_LINE_B: R65.1, R66.2; also elsewhere on the board
GND: AMP1.P$3 (M1), AMP1.P$4 (M2), AMP1.P$12 (GND), AMP1.P$13 (GND), AMP1.P$25 (GND), AMP1.P$26 (GND), AMP1.P$33 (GND), AMP1.P$34 (GND), AMP1.P$41 (GND), AMP1.P$42 (GND), C7.1, C54.2, C55.2, C56.2, C57.2, C58.2, C59.-, C60.-, C61.2, C62.2, C63.2, C64.2, C65.2, C66.2, C67.2, C68.2, C69.2, C70.2, C75.1, C76.1, C81.1, C82.1, C83.2, C84.2, IC2.4 (V-), IC3.4 (V-), R50.1, R51.1, R59.1, R66.1, R70.1; also elsewhere on the board
unnamed: AMP1.P$15 (C_START), C7.2
unnamed: AMP1.P$8 (FREQ_ADJ), R50.2
unnamed: AMP1.P$7 (OC_ADJ), R51.2
unnamed: AMP1.P$18 (!RESET), R52.2
unnamed: AMP1.P$20 (VBG), C54.1
unnamed: AMP1.P$11 (DVDD), C61.1
unnamed: AMP1.P$14 (AVDD), C62.1
unnamed: AMP1.P$1 (GVDD_AB), C65.1, R54.2
unnamed: AMP1.P$2 (VDD), C64.1, L4.2
unnamed: AMP1.P$22 (GVDD_CD), C63.1, R53.2
unnamed: C71.1, IC2.2 (-IN), R57.1, R58.2
unnamed: C71.2, C74.1, IC2.1 (OUT), R55.1, R57.2
unnamed: C72.1, IC2.6 (-IN), R55.2, R56.1
unnamed: C77.1, IC3.2 (-IN), R64.1, R65.2
unnamed: C72.2, C73.1, IC2.7 (OUT), R56.2
unnamed: C77.2, C80.1, IC3.1 (OUT), R62.1, R64.2
unnamed: C78.1, IC3.6 (-IN), R62.2, R63.1
unnamed: C74.2, R61.1
unnamed: C73.2, R60.1
unnamed: C78.2, C79.1, IC3.7 (OUT), R63.2
unnamed: C80.2, R68.1
unnamed: C79.2, R67.1
V+: AMP1.P$29 (PVDD_CD), AMP1.P$30 (PVDD_CD), AMP1.P$31 (PVDD_CD), AMP1.P$36 (PVDD_AB), AMP1.P$37 (PVDD_AB), AMP1.P$38 (PVDD_AB), C55.1, C56.1, C57.1, C58.1, C59.+, C60.+; also elsewhere on the board
VMID: C83.1, C84.1, IC2.3 (+IN), IC2.5 (+IN), IC3.3 (+IN), IC3.5 (+IN), R69.2, R70.2

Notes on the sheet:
Ch. A+B Amplifier
PVDD Bypass
Mode hardwired to 2xBTL (Stereo)
OpAmp voltage supply + bypass
Input Peripherals


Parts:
C85, C86, C87, C88, C97, C98, C107, C108: 1µF; C150-091X182
C89, C90, C93, C94, C99, C100, C111, C112: 1000pF; C0805
C91, C92, C101, C102, C103, C104, C113, C114: 100nF; C0805
C95, C96, C105, C106, C109, C110, C115, C116: 33nF; C0603
L6, L7, L8, L9, L10, L11, L12, L13: HTCI-10-20.0; HCTI-10-20.0
R71, R72, R73, R74, R75, R76, R77, R78: 3.3Ω; R0603

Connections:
AMP1_BST_A: C109.1; also elsewhere on the board
AMP1_BST_B: C110.1; also elsewhere on the board
AMP1_BST_C: C95.1; also elsewhere on the board
AMP1_BST_D: C96.1; also elsewhere on the board
AMP1_PWM_A: C109.2, L6.P$1 (1); also elsewhere on the board
AMP1_PWM_B: C110.2, L7.P$1 (1); also elsewhere on the board
AMP1_PWM_C: C95.2, L8.P$1 (1); also elsewhere on the board
AMP1_PWM_D: C96.2, L9.P$1 (1); also elsewhere on the board
AMP2_BST_A: C105.1; also elsewhere on the board
AMP2_BST_B: C106.1; also elsewhere on the board
AMP2_BST_C: C115.1; also elsewhere on the board
AMP2_BST_D: C116.1; also elsewhere on the board
AMP2_PWM_A: C105.2, L10.P$1 (1); also elsewhere on the board
AMP2_PWM_B: C106.2, L11.P$1 (1); also elsewhere on the board
AMP2_PWM_C: C115.2, L12.P$1 (1); also elsewhere on the board
AMP2_PWM_D: C116.2, L13.P$1 (1); also elsewhere on the board
GND: C85.2, C86.2, C87.2, C88.2, C89.2, C90.2, C93.2, C94.2, C97.2, C98.2, C99.2, C100.2, C107.2, C108.2, C111.2, C112.2, R71.2, R72.2, R73.2, R74.2, R75.2, R76.2, R77.2, R78.2; also elsewhere on the board
unnamed: C92.2, R74.1
unnamed: C102.2, R72.1
unnamed: C101.2, R71.1
unnamed: C91.2, R73.1
unnamed: C104.2, R76.1
unnamed: C103.2, R75.1
unnamed: C114.2, R78.1
unnamed: C113.2, R77.1
OUT_A_+: C85.1, C93.1, C101.1, L6.P$2 (2); also elsewhere on the board
OUT_A_-: C86.1, C94.1, C102.1, L7.P$2 (2); also elsewhere on the board
OUT_B_+: C87.1, C89.1, C91.1, L8.P$2 (2); also elsewhere on the board
OUT_B_-: C88.1, C90.1, C92.1, L9.P$2 (2); also elsewhere on the board
OUT_C_+: C97.1, C99.1, C103.1, L10.P$2 (2); also elsewhere on the board
OUT_C_-: C98.1, C100.1, C104.1, L11.P$2 (2); also elsewhere on the board
OUT_D_+: C107.1, C111.1, C113.1, L12.P$2 (2); also elsewhere on the board
OUT_D_-: C108.1, C112.1, C114.1, L13.P$2 (2); also elsewhere on the board

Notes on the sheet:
Ch. A + B + C + D Output filter


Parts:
AMP2: TPA3255-Q1; HTSSOP44
C117: 47nF; C0603
C118, C119, C120, C121, C122, C123, C129, C130, C131, C133, C147: 1µF; C3216
C124, C125: 4700µF; EB22,5D
C126, C127, C128, C132, C134, C139, C140, C145, C146, C148: 100nF; C0603
C135, C136, C141, C142: 22pF; C0603
C137, C138, C143, C144: 10µF; C3216
IC4, IC5: NE5532D; SO08
L14, L15: L-USL2012C; L2012C
R79: 30kΩ; R0603
R80: 22kΩ; R0603
R81, R84, R85, R86, R87, R91, R92, R93, R94, R98, R99: 10kΩ; R0603
R82, R83: 0Ω; R0603
R88, R95: 100kΩ; R0603
R89, R90, R96, R97: 100Ω; R0603

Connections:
+3V3: R81.1; also elsewhere on the board
+12V: L14.1, L15.1, R82.1, R83.1; also elsewhere on the board
+12VOA1: C130.1, C131.1, C132.1, C133.1, C134.1, IC4.8 (V+), IC5.8 (V+), L15.2, R98.1
AMP2_BST_A: AMP2.P$44 (BST_A); also elsewhere on the board
AMP2_BST_B: AMP2.P$43 (BST_B); also elsewhere on the board
AMP2_BST_C: AMP2.P$24 (BST_C); also elsewhere on the board
AMP2_BST_D: AMP2.P$23 (BST_D); also elsewhere on the board
AMP2_CLIP_OTW: AMP2.P$21 (!CLIP_OTW); also elsewhere on the board
AMP2_FAULT: AMP2.P$19 (!FAULT); also elsewhere on the board
AMP2_IN_A: AMP2.P$5 (INPUT_A), C140.2, R90.2
AMP2_IN_B: AMP2.P$6 (INPUT_B), C139.2, R89.2
AMP2_IN_C: AMP2.P$16 (INPUT_C), C146.2, R97.2
AMP2_IN_D: AMP2.P$17 (INPUT_D), C145.2, R96.2
AMP2_PWM_A: AMP2.P$39 (OUT_A), AMP2.P$40 (OUT_A); also elsewhere on the board
AMP2_PWM_B: AMP2.P$35 (OUT_B); also elsewhere on the board
AMP2_PWM_C: AMP2.P$32 (OUT_C); also elsewhere on the board
AMP2_PWM_D: AMP2.P$27 (OUT_D), AMP2.P$28 (OUT_D); also elsewhere on the board
A_LINE_C: R87.1, R88.2; also elsewhere on the board
A_LINE_D: R94.1, R95.2; also elsewhere on the board
GND: AMP2.P$3 (M1), AMP2.P$4 (M2), AMP2.P$12 (GND), AMP2.P$13 (GND), AMP2.P$25 (GND), AMP2.P$26 (GND), AMP2.P$33 (GND), AMP2.P$34 (GND), AMP2.P$41 (GND), AMP2.P$42 (GND), C117.1, C118.2, C119.2, C120.2, C121.2, C122.2, C123.2, C124.-, C125.-, C126.2, C127.2, C128.2, C129.2, C130.2, C131.2, C132.2, C133.2, C134.2, C139.1, C140.1, C145.1, C146.1, C147.2, C148.2, IC4.4 (V-), IC5.4 (V-), R79.1, R80.1, R88.1, R95.1, R99.1; also elsewhere on the board
unnamed: AMP2.P$8 (FREQ_ADJ), R79.2
unnamed: AMP2.P$15 (C_START), C117.2
unnamed: AMP2.P$7 (OC_ADJ), R80.2
unnamed: AMP2.P$18 (!RESET), R81.2
unnamed: AMP2.P$20 (VBG), C129.1
unnamed: AMP2.P$11 (DVDD), C118.1
unnamed: AMP2.P$14 (AVDD), C119.1
unnamed: AMP2.P$1 (GVDD_AB), C128.1, R83.2
unnamed: AMP2.P$2 (VDD), C127.1, L14.2
unnamed: AMP2.P$22 (GVDD_CD), C126.1, R82.2
unnamed: C135.1, IC4.2 (-IN), R86.1, R87.2
unnamed: C135.2, C138.1, IC4.1 (OUT), R84.1, R86.2
unnamed: C136.1, IC4.6 (-IN), R84.2, R85.1
unnamed: C136.2, C137.1, IC4.7 (OUT), R85.2
unnamed: C138.2, R90.1
unnamed: C137.2, R89.1
unnamed: C141.1, IC5.2 (-IN), R93.1, R94.2
unnamed: C141.2, C144.1, IC5.1 (OUT), R91.1, R93.2
unnamed: C142.1, IC5.6 (-IN), R91.2, R92.1
unnamed: C142.2, C143.1, IC5.7 (OUT), R92.2
unnamed: C144.2, R97.1
unnamed: C143.2, R96.1
V+: AMP2.P$29 (PVDD_CD), AMP2.P$30 (PVDD_CD), AMP2.P$31 (PVDD_CD), AMP2.P$36 (PVDD_AB), AMP2.P$37 (PVDD_AB), AMP2.P$38 (PVDD_AB), C120.1, C121.1, C122.1, C123.1, C124.+, C125.+; also elsewhere on the board
VMID1: C147.1, C148.1, IC4.3 (+IN), IC4.5 (+IN), IC5.3 (+IN), IC5.5 (+IN), R98.2, R99.2

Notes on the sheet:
Ch. C + D Amplifier
PVDD Bypass
Mode hardwired to 2xBTL (Stereo)
OpAmp voltage supply + bypass
Input Peripherals



Board: 2 copper layers, 200.0 x 150.0 mm, 322 parts (70 on the bottom side), 199 nets.

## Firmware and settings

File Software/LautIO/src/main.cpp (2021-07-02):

/*
 *
 * This file is part of LautIO
 * 
 * Copyright 2021 - olel
 * LautIO is licensed under MIT License
 * See LICENSE file for more information
 * 
 */

#include <Arduino.h>

// utils
#include "util/log.h"
#include "util/config.h"
#include "util/ftp.h"
#include "util/http.h"
#include "util/websockets.h"

// interfaces
#include "util/interfaces/com.h"
#include "util/interfaces/amp.h"

// drivers
#include "driver/amp.h"
#include "driver/filesystem.h"
#include "driver/wifi.h"
#include "driver/battery.h"
#include "driver/dsp.h"

void setup() {

    // Pin Modes for stuff without dedicated driver
    pinMode(SYS_LED_PIN, OUTPUT);

    // System setup, starting with logging
    init_logging();
    log_info("Starting system setup!");
    init_amps(); // Starting amps first to prevent potential damages
    init_filesystem();
    Configuration::get_instance(); // Getting an instance to initialise
    init_wifi();
    init_battery();
    init_ftp_server();
    init_dsp();
    init_http(); // inits http & websockets

    float vbat = get_battery_voltage();
    log_info("Current battery voltage %.02fV", vbat);
}

void loop() {
    // Try to do the most thing async.. but repeating stuff here
    ftp_server_loop();
    websocket_loop();
}

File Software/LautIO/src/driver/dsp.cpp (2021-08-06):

/*
 *
 * This file is part of LautIO
 * 
 * Copyright 2021 - olel
 * LautIO is licensed under MIT License
 * See LICENSE file for more information
 * 
 */

#include "sys_config.h"

#include "SigmaDSP.h"
#include <Wire.h>
#include "ArduinoJson.h"

// util
#include "util/log.h"
#include "util/config.h"

// driver
#include "driver/dsp.h"
#include "driver/filesystem.h" // to load firmware from fs

// dsp register size / addr vars
uint16_t cr0_size, cr0_addr;
uint16_t cr4_size, cr4_addr;
uint16_t program_size, program_addr;
uint16_t param_size, param_addr;
uint16_t hwconf_size, hwconf_addr;

uint8_t* cr0_data;
uint8_t* cr4_data;
uint8_t* program_data;
uint8_t* param_data;
uint8_t* hwconf_data;

SigmaDSP dsp(Wire, DSP_I2C_ADDRESS, 48000.00f, DSP_RESET_PIN);

DynamicJsonDocument dsp_controls(2048); // maybe to small..

char current_fw_name[64];

void init_dsp() {
    // initialise dsp
    log_info("Initialising DSP");

    Wire.begin();
    log_debug("Started wire");
    dsp.begin();
    log_debug("Started dsp");

    log_debug("Waiting a sec for DSP to come up");
    delay(1000);

    if (dsp_ping()) {
        log_info("DSP ping successful!");
    }
    else {
        log_fatal("Failed to ping DSP, please restart");
        ESP.deepSleep(0); // Put into deepsleep, basically halt
    }

    dsp_change_firmware((const char*) Configuration::section("dsp")["default_firmware"]);

}


bool dsp_ping() {
    // Ping one time and get success status
    return dsp.ping() == 0;
}

void dsp_load_data(const char* dirname) {
    log_info("Loading dsp data from directory %s", dirname);

    // loading sizes and addresses from register.json file
    char file_path[32]; // will be reused
    sprintf(file_path, "/dsp/%s/registers.json", dirname);
    File reg_file = FSHANDLE.open(file_path);
    StaticJsonDocument<512> register_json;
    DeserializationError e = deserializeJson(register_json, reg_file);
    if (e) {
        log_fatal("Failed to load registers.json from dsp firmware!");
        log_fatal(": %s", e.c_str());
        ESP.deepSleep(0);
    }
    cr0_addr = register_json["cr0"][0];
    cr0_size = register_json["cr0"][1];
    cr4_addr = register_json["cr4"][0];
    cr4_size = register_json["cr4"][1];
    param_addr = register_json["param"][0];
    param_size = register_json["param"][1];
    hwconf_addr = register_json["hwconf"][0];
    hwconf_size = register_json["hwconf"][1];
    program_addr = register_json["program"][0];
    program_size = register_json["program"][1];

    // free unused data
    reg_file.close();
    register_json.clear();
    
    log_debug("Loaded register size/addr file");
    log_debug("| REGISTER | ADDR | SIZE |");
    log_debug("|----------|------|------|");
    log_debug("|      CR0 | %4d | %4d |", cr0_addr, cr0_size);
    log_debug("|      CR4 | %4d | %4d |", cr4_addr, cr4_size);
    log_debug("|   HWCONF | %4d | %4d |", hwconf_addr, hwconf_size);
    log_debug("|    PARAM | %4d | %4d |", param_addr, param_size);
    log_debug("|  PROGRAM | %4d | %4d |", program_addr, program_size);

    // load register data from seperate files

    // allocate memory
    cr0_data = (uint8_t*) malloc(cr0_size);
    cr4_data = (uint8_t*) malloc(cr4_size);
    param_data = (uint8_t*) malloc(param_size);
    hwconf_data = (uint8_t*) malloc(hwconf_size);
    program_data = (uint8_t*) malloc(program_size);

    log_debug("Allocated memory for dsp firmware");

    // load program file
    sprintf(file_path, "/dsp/%s/program.bin", dirname);
    File program_file = FSHANDLE.open(file_path);
    uint16_t addr = 0;
    while(program_file.available()) {
        program_data[addr] = program_file.read();
        addr ++;
    }
    log_debug("Loaded program data");
    program_file.close();

    // load param file
    sprintf(file_path, "/dsp/%s/param.bin", dirname);
    File param_file = FSHANDLE.open(file_path);
    addr = 0;
    while(param_file.available()) {
        param_data[addr] = param_file.read();
        addr ++;
    }
    log_debug("Loaded param data");
    param_file.close();

    // load cr0 file
    sprintf(file_path, "/dsp/%s/cr0.bin", dirname);
    File cr0_file = FSHANDLE.open(file_path);
    addr = 0;
    while(cr0_file.available()) {
        cr0_data[addr] = cr0_file.read();
        addr ++;
    }
    log_debug("Loaded cr0 data");
    cr0_file.close();

    // load cr4 file
    sprintf(file_path, "/dsp/%s/cr4.bin", dirname);
    File cr4_file = FSHANDLE.open(file_path);
    addr = 0;
    while(cr4_file.available()) {
        cr4_data[addr] = cr4_file.read();
        addr ++;
    }
    log_debug("Loaded cr4 data");
    cr4_file.close();

    // load hwconf file
    sprintf(file_path, "/dsp/%s/hwconf.bin", dirname);
    File hwconf_file = FSHANDLE.open(file_path);
    addr = 0;
    while(hwconf_file.available()) {
        hwconf_data[addr] = hwconf_file.read();
        addr ++;
    }
    log_debug("Loaded hwconf data");
    hwconf_file.close();

}

void dsp_upload_firmware() {
    // upload firmware to dsp
    log_info("Uploading firmware to dsp");
    dsp.writeRegister(cr0_addr, cr0_size, cr0_data);
    log_debug("Uploaded CR0 data");
    dsp.writeRegisterBlock(program_addr, program_size, program_data, PROGRAM_REGSIZE);
    log_debug("Uploaded PROGRAM data");
    dsp.writeRegisterBlock(param_addr, param_size, param_data, PARAM_REGSIZE);
    log_debug("Uplaoded PARAM data");
    dsp.writeRegister(hwconf_addr, hwconf_size, hwconf_data);
    log_debug("Uploaded HWCONF data");
    dsp.writeRegister(cr4_addr, cr4_size, cr4_data);
    log_debug("Uploaded CR4 data, all done!");
    log_info("Uploaded data!");
}

void dsp_free_firmware() {
    free(cr0_data);
    free(cr4_data);
    free(param_data);
    free(hwconf_data);
    free(program_data);
}

void dsp_load_controls(const char* dirname) {
    log_info("Loading dsp controls");
    char filename[32];
    sprintf(filename, "/dsp/%s/controls.json", dirname);
    File controls_file = FSHANDLE.open(filename);
    DeserializationError e = deserializeJson(dsp_controls, controls_file);
    if (e) {
        log_fatal("Failed to load controls.. dsp controls will not be available!");
        log_debug("Fail reason: %s", e.c_str());
    }
    log_debug("loaded controls. %d controls found!", dsp_controls["controls"].size());
}

void dsp_write_controls(const char* dirname) {
    log_info("Writing dsp controls (%s)", dirname);
    char filename[32];
    sprintf(filename, "/dsp/%s/controls.json", dirname);
    File controls_file = FSHANDLE.open(filename, "w");
    serializeJson(dsp_controls, Serial);
    serializeJson(dsp_controls, controls_file);
    controls_file.close();
    log_debug("Controls saved :)");
}
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

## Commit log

2021-03-09 Added some files
    [BOM.ods, LautIO.brd, LautIO.sch]
2021-03-09 Added pdf schematics
2021-03-11 Final Proto V1 hardware filse
    [LautIO.brd, LautIO.sch]
2021-03-11 updated bom
    [BOM.ods]
2021-03-17 Add: Wifi driver
2021-03-17 Started implementing filesystem driver
2021-03-31 Updated to hotfixed dsp reset pin
2021-03-31 Added wire dep
2021-04-01 Updated pin definition names
2021-04-04 started implementing dsp driver
2021-04-05 Started implementing dsp web controls
    [controls.csv]
2021-04-06 changed controls file from csv to json
    [controls.csv]
2021-04-09 Added dark mode switch
2021-04-09 Implemented missing soeq controls
    [dsp.cpp]
2021-04-21 Added FILESYSTEM_TYPE switch
2021-04-21 Added filesystem driver - implementing SPIFFS
2021-04-30 Added new hardware files
    [BOM.ods, LautIO.brd, LautIO.sch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]
2021-05-03 Started implementing amp driver
2021-05-03 Implemented sd card driver stuff
2021-05-03 Added reference to arduinojson library
2021-05-03 Added sample config file
2021-05-03 Implemented config driver
2021-05-03 Switched this back
2021-05-03 Started implementing wifi driver
2021-05-03 moved wifi to driver
2021-05-04 Designed Heatpipe Mount
    [pipemount.dxf, pipemount.scad]
2021-05-05 Implemented Battery Measurement
2021-05-06 Added mute adc/dac as control type
2021-05-06 Mute ADC implemented
2021-05-06 removed id param from adc/dac mute
2021-05-16 Moved some files + panels
    [pipemount.dxf, pipemount.scad]
2021-05-17 Updated hardware config to current prototype
2021-05-20 Added case design files
    [panel_front_cutouts.dxf, panel_rear_cutouts.dxf]
2021-05-30 Changed dep to current git version
2021-05-30 Added case rendering images
2021-05-31 Fixed vbat read offset
    [battery.h]
2021-05-31 Added battery voltage to boot log
2021-07-14 Ui config + quick control filtering
2021-07-18 Added both amp on/off switches
2021-07-20 Added missing filter types
2021-10-12 Added settings page w/ debug button

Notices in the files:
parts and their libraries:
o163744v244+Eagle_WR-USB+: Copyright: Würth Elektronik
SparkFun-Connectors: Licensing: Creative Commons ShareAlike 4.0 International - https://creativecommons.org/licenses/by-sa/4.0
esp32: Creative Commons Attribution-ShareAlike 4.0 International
